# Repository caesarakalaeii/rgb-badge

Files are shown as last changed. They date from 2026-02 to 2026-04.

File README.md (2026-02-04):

# Ultra-High-Density RGB Matrix Badge

A wearable RGB matrix badge featuring 2560 individually addressable LEDs in a compact 100×65mm form factor.

## Project Overview

This project implements an ultra-dense LED matrix badge designed for human viewing (not camera-optimized) with parallel data lanes to achieve smooth 60+ FPS refresh rates. The design uses a two-board architecture separating the dense LED matrix from controller/power electronics for improved manufacturability and maintainability.

### Key Specifications

| Parameter | Value |
|---|---|
| Display Area | 100 mm × 65 mm |
| Resolution | 64 × 40 pixels (2560 total) |
| Pixel Pitch | 1.5625 mm (X) × 1.625 mm (Y) |
| Target Refresh Rate | 60+ FPS |
| Power Source | USB-C PD Powerbank |
| Quantity | ~10 boards |
| PCB Tool | KiCad |

## Hardware Architecture

### Two-Board Design

#### 1. Matrix PCB
- Dense 64×40 LED array
- Power distribution network
- Extensive decoupling capacitors
- Data lane entry points (8 lanes)
- Optimized for minimal rework risk

#### 2. Controller/Power PCB
- ESP32-S3 microcontroller
- USB-C Power Delivery circuitry
- Buck converter (PD voltage → 5V)
- 3.3V regulator for MCU
- Level shifters (3.3V → 5V for LED data)
- Power switch and protection
- Easy to iterate/upgrade without risking LED matrix

**Rationale:** Separating control from display allows safe iteration on USB/PD/MCU without risking the expensive, dense LED field.

## Component Selection

### LED: XINGLIGHT XL-1010RGBC-2812B

**Why this LED:**
- Cost: ~€0.03/pixel at volume (extremely competitive)
- Package: 1.0×1.0×0.8 mm (1010 SMD)
- Protocol: WS2812B-compatible (1-wire smart RGB)
- Supply: 3.5–5.5V (100% functional at 4.5–5.5V)
- PWM: ~1.0 kHz, 256 grayscale steps per channel
- Timing: ~1.2 µs per bit (~800 kbps class)

**Electrical Characteristics:**
- VDD: 3.5–5.5V (running at 5V)
- DIN VIH (min): 2.8V, VIL (max): 1.6V
- Optimized current: ~5 mA/channel → ~15 mA/pixel at full white
- Full array theoretical max: 2560 × 15 mA = 38.4A @ 5V (192W)

**Footprint Details:**
- 4× corner pads, 0.40 mm × 0.40 mm each
- Body-to-body clearance: ~0.56–0.63 mm at chosen pitch
- Minimal courtyard required for dense packing

### Microcontroller: ESP32-S3

**Selection criteria:**
- Sufficient GPIO for 8+ parallel data lanes
- DMA-capable for smooth LED updates
- Good headroom for complex animations
- 3.3V I/O (requires level shifting to 5V LEDs)
- Well-supported by Arduino/ESP-IDF ecosystems

### Power Architecture

#### Strategy: PD Negotiation → Buck Conversion

```
USB-C PD Powerbank (25000mAh, 145W class)
    ↓ (negotiated at 9V baseline, 12V/15V/20V optional)
Buck Converter
    ↓ (5V rail for LEDs)
LED Matrix (capped brightness in firmware)
    +
    ↓ (3.3V regulator)
ESP32-S3 + Logic
```

**PD Voltage Selection:**
- **Baseline: 9V PD** (maximum compatibility)
- Higher voltages (12V/15V/20V) reduce cable current but may not be universally available
- Buck converter sized for 8–12A continuous @ 5V (40–60W with safety margin)

**Rationale:**
- Reduces cable/connector current stress
- Provides stable 5V rail despite powerbank voltage
- Allows brightness capping in firmware to manage realistic power draw

## Data Distribution Architecture

### 8-Lane Parallel Design

**Mapping:**
- 8 data lanes, each driving 320 pixels
- Each lane: 8 columns × 40 rows
- Lanes arranged as vertical stripes across the 64-column display

**Refresh Math (per lane):**
```
1 pixel = 24 bits × 1.2 µs ≈ 28.8 µs
320 pixels ≈ 9.22 ms
+ Reset time (>200 µs) ≈ 9.4–9.8 ms total
→ Max refresh ≈ 100+ FPS per lane
```

**Actual target:** 60 FPS with comfortable headroom

### Signal Integrity

#### Level Shifting
- ESP32 outputs: 3.3V logic
- LED inputs: require high VIH @ 5V supply
- Solution: Fast 3.3V→5V level shifters, one per lane

#### Series Resistors (Multi-Purpose Protection)

**At level shifter output:**
- 33–68Ω close to shifter
- Purpose: Signal integrity, prevent overshoot/ringing on short traces

**Optional at matrix connector:**
- 220–500Ω (stuff if needed)
- Purpose: Protection against live-plug transients, cable inductance
- Datasheet recommends "protective resistors" and mentions 20Ω–2kΩ range

## PCB Design Considerations (KiCad)

### Matrix PCB Layout

#### LED Footprint Settings
```
Pads: 4× corner pads, 0.40mm × 0.40mm
Courtyard: Minimal (allow overlap for dense packing)
Soldermask: Conservative expansion per fab limits
Pitch: 1.5625mm (X) × 1.625mm (Y)
```

#### Placement Strategy
1. Create LED footprint with tight courtyard
2. Place first LED
3. Use **Rectangular Array Placement** for 64×40 grid
4. Disable clearance outline visualization in Appearance panel if needed
5. Verify soldermask web meets fab minimums

#### Decoupling Strategy

**Datasheet requirement:** "Decoupling capacitance between each LED is essential"

**Practical options:**
- **Aggressive:** 0201 ceramic per LED (2560 caps, likely on backside)
- **Practical:** Small cluster caps + per-lane bulk capacitors
- Requires via strategy for backside placement or dense front-side routing

### Power Distribution

**Primary concern:** Transients and current steps, not just average power

**Design for:**
- Fast load steps as LEDs switch between frames
- Large bulk capacitance on 5V rail near buck converter
- Low-impedance power distribution across matrix
- Star or mesh power routing to minimize voltage drop

**Enforcement:** Global brightness limiting in firmware to prevent exceeding powerbank capability

## Manufacturing Constraints

### Reflow Profile (from LED datasheet)
- Peak temperature: 260°C for 6 seconds maximum
- Maximum reflow cycles: 2
- **Implication:** Don't risk matrix board with unnecessary rework

### Hand Soldering (rework only)
- Iron: <30W, <300°C
- Contact time: <3 seconds per terminal
- **One touch per terminal maximum**

### Moisture Sensitivity
- Store sealed with desiccant
- After opening: use quickly in low humidity
- If compromised: bake at 60°C for 24 hours before use

**Recommendation:** Order LEDs in moisture-barrier bags, open only when ready for assembly, and complete assembly quickly.

## Development Roadmap

### Current Status: Design Phase

#### Completed
- [x] LED selection and validation
- [x] Architecture decisions (two-board, 8-lane)
- [x] Power strategy (PD negotiation + buck)
- [x] Footprint specifications from datasheet
- [x] Signal integrity approach

#### Next Steps

1. **KiCad Footprint Finalization**
   - Create LED footprint with datasheet-verified pad geometry
   - Validate courtyard settings for dense array placement
   - Test rectangular array placement for 64×40 grid

2. **Power Tree Design**
   - Define brightness cap (e.g., max 20W from bank)
   - Size buck converter and output capacitors
   - Calculate per-lane bulk capacitor requirements
   - Design power distribution network for matrix PCB

3. **Interconnect Definition**
   - Choose physical connection method (board-to-board, flex, cable)
   - Design lane-entry routing convention
   - Finalize connector footprints

4. **Schematic & Layout**
   - Controller/Power PCB schematic
   - Matrix PCB schematic (8 lane entry points + power)
   - Both PCB layouts with careful attention to:
     - Power distribution impedance
     - Signal integrity on data lanes
     - Thermal management (buck converter)
     - Mechanical alignment between boards

5. **Firmware Architecture**
   - ESP32-S3 parallel output driver using DMA
   - Brightness limiting enforcement
   - Animation framework
   - USB power negotiation handling

6. **Prototype & Test**
   - Order small batch (1-2 sets)
   - Validate assembly process
   - Test refresh rates and power consumption
   - Iterate before production run

## Bill of Materials (Estimated)

| Component | Quantity | Unit Cost | Total |
|---|---|---|---|
| XL-1010RGBC-2812B LED | 2560 | €0.03 | €76.80 |
| ESP32-S3 Module | 1 | ~€5 | €5 |
| Buck Converter IC + passives | 1 | ~€2-5 | €3.50 |
| Level Shifters (8ch) | 1-2 | ~€1 | €2 |
| PCBs (Matrix + Controller) | 2 | ~€30-50 | €40 |
| Connectors, passives, misc | - | - | €10-20 |
| **Total per badge (estimate)** | | | **~€140-150** |

*Note: Costs are rough estimates and will vary with supplier, quantity, and shipping.*

## References

- LED Datasheet: XINGLIGHT XL-1010RGBC-2812B (WS2812B protocol)
- MCU: ESP32-S3 Technical Reference Manual
- Target Powerbank: UGREEN Nexode 145W Max 25000mAh (or equivalent USB-C PD)

## Design Philosophy

**Key Principles:**
1. **Human-optimized, not camera-optimized** – No special PWM requirements for video compatibility
2. **Maintainability over integration** – Two-board design allows safe iteration
3. **Parallel over serial** – 8 data lanes enable smooth refresh without exotic protocols
4. **Design for manufacturing** – Minimize rework risk on dense LED matrix
5. **Power awareness** – Design for transients and steps, enforce limits in firmware

## License

This project is licensed under the GNU Affero General Public License v3.0 (AGPL-3.0) - see the [LICENSE](LICENSE) file for details.

## Contributors

- [@caesarakalaeii](https://github.com/caesarakalaeii) - Project creator and maintainer

---

**Project Status:** Active Development
**Last Updated:** 2026-02-04

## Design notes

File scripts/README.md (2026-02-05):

# KiCad LED Matrix Placement Scripts

Python scripts for automated placement of the 40×64 LED matrix in KiCad PCB Editor with VIA-optimized power distribution.

## Quick Start

### 1. Basic Placement Script

**File:** `place_led_matrix.py`

Simple row-major placement (left-to-right, top-to-bottom).

**Usage:**
1. Open your PCB in KiCad PCB Editor
2. Open scripting console: Tools → Scripting Console
3. Run:
   ```python
   exec(open('scripts/place_led_matrix.py').read())
   ```

### 2. Advanced Placement Script

**File:** `place_led_matrix_advanced.py`

Supports multiple placement patterns including the 8-lane serpentine pattern recommended in the README.

**Usage:**
1. Edit the script to choose your pattern:
   ```python
   PLACEMENT_PATTERN = "8lane_serpentine"  # or "row_major" or "serpentine"
   ```
2. Adjust starting position if needed:
   ```python
   START_X = 10.0  # mm from board origin
   START_Y = 10.0  # mm from board origin
   ```
3. Run in KiCad Scripting Console:
   ```python
   exec(open('scripts/place_led_matrix_advanced.py').read())
   ```

### 3. VIA-Optimized Placement Script (Recommended)

**File:** `place_led_matrix_via_optimized.py`

Optimized LED placement for shared power VIAs with 2×2 LED block pattern.

**Features:**
- 40 columns × 64 rows = 2560 LEDs
- 8 data lanes, each handling 8 rows × 40 columns (320 LEDs per lane)
- Serpentine routing within each lane for optimal data flow
- LEDs rotated in 2×2 blocks so VDD/GND pins face center
- Enables one shared VIA per 4 LEDs (640 VIAs total vs 2560)

**Target Pin Arrangement (2×2 block with center VIA):**
```
2 4 | 1 2
1 3 | 3 4
----V----
4 3 | 3 1
2 1 | 4 2
```
Where: 1=DOUT, 2=VDD, 3=GND, 4=DIN, V=shared VIA

**Usage:**
1. Adjust starting position and verify rotation angles:
   ```python
   START_X = 10.0
   START_Y = 10.0

   # Verify these match your footprint orientation
   BLOCK_ROTATIONS = {
       (True, True):   -90,   # Top-left
       (False, True):    0,   # Top-right
       (True, False):  180,   # Bottom-left
       (False, False):  90,   # Bottom-right
   }
   ```
2. Run in KiCad Scripting Console:
   ```python
   exec(open('scripts/place_led_matrix_via_optimized.py').read())
   ```
3. Verify LED orientations visually
4. Adjust BLOCK_ROTATIONS if pins don't align correctly

### 4. Shared VIA Placement Script

**File:** `place_power_vias.py`

Automatically places power VIAs in the center of each 2×2 LED block.

**Usage:**
1. **Run AFTER** running `place_led_matrix_via_optimized.py`
2. Verify configuration matches LED placement:
   ```python
   LED_COLS = 40
   LED_ROWS = 64
   VIA_SIZE = 0.4    # mm diameter
   VIA_DRILL = 0.2   # mm drill
   ```
3. Run in KiCad Scripting Console:
   ```python
   exec(open('scripts/place_power_vias.py').read())
   ```
4. Manually assign VIAs to VDD or GND nets as needed
5. Add power planes or heavy traces between VIAs

## Placement Patterns

### Row Major
- Simple left-to-right, top-to-bottom
- LED1 at top-left, LED2560 at bottom-right
- Longest data paths

### Serpentine
- Alternates direction each row
- Reduces trace length between rows
- Better for single-lane designs

### 8-Lane Serpentine (Recommended)
- Matches the README's 8 parallel data lanes architecture
- Each lane handles 8 columns × 40 rows (320 pixels)
- Serpentine routing within each lane
- Optimal for the parallel data distribution design

## Configuration

### For VIA-Optimized Scripts (Recommended)

Edit these variables in `place_led_matrix_via_optimized.py`:

```python
# Matrix size (VIA-optimized layout)
COLS = 40   # 40 columns
ROWS = 64   # 64 rows (8 data lanes × 8 rows each)
PITCH_X = 1.5625  # mm
PITCH_Y = 1.625   # mm

# Starting position (adjust for your board)
START_X = 10.0  # mm
START_Y = 10.0  # mm

# LED reference prefix (e.g., "D" for D1, D2, ...)
LED_PREFIX = "D"

# Block rotations for VIA optimization
BLOCK_ROTATIONS = {
    (True, True):   -90,   # Top-left LED in each 2×2 block
    (False, True):    0,   # Top-right LED
    (True, False):  180,   # Bottom-left LED
    (False, False):  90,   # Bottom-right LED
}
```

### For Legacy Scripts

Edit these variables in `place_led_matrix.py` or `place_led_matrix_advanced.py`:

```python
# Matrix size (legacy layout)
COLS = 64
ROWS = 40
PITCH_X = 1.5625  # mm
PITCH_Y = 1.625   # mm

# Starting position (adjust for your board)
START_X = 10.0  # mm
START_Y = 10.0  # mm

# LED reference prefix (e.g., "D" for D1, D2, ...)
LED_PREFIX = "D"

# Rotation (degrees)
LED_ROTATION = 0.0
```

## Prerequisites

### Footprint Naming
LEDs must be named sequentially:
- LED1, LED2, LED3, ..., LED2560

### Component Import
Before running placement:
1. Create schematic with 2560 LED symbols
2. Assign footprints to all LEDs
3. Update PCB from schematic (Tools → Update PCB from Schematic)
4. All 2560 LEDs should now be on the PCB (likely in a pile)

## Workflow

### Method 1: VIA-Optimized Workflow (Recommended)

1. **Design schematic** with 2560 LED symbols
   - Use hierarchical sheets or array annotations if needed
   - Assign XL-1010RGBC-2812B footprint to all
   - Add connectors: J1 (data lines) and J2 (VDD/GND)

2. **Update PCB from schematic**
   - All LEDs import as a stack at origin

3. **Run LED placement script**
   - `exec(open('scripts/place_led_matrix_via_optimized.py').read())`
   - Verify LED orientations match intended 2×2 block pattern

4. **Run VIA placement script**
   - `exec(open('scripts/place_power_vias.py').read())`
   - Places 640 shared VIAs in 2×2 block centers

5. **Power distribution**
   - Assign VIAs to VDD/GND nets
   - Add power planes on inner layers
   - Connect J2 (power connector) to power distribution

6. **Data routing**
   - Route 8 data lanes from J1 (data connector)
   - Each lane: 8 rows × 40 LEDs in serpentine pattern
   - Add series resistors on data lines if needed

### Method 2: Legacy Import then Auto-Place

1. **Design schematic** with 2560 LED symbols
   - Use hierarchical sheets or array annotations if needed
   - Assign XL-1010RGBC-2812B footprint to all

2. **Update PCB from schematic**
   - All LEDs import as a stack at origin

3. **Run placement script**
   - Opens them into perfect matrix

4. **Route**
   - Add data traces, power planes, decoupling caps

### Method 2: Place-as-you-go

1. Place first LED manually at desired start position
2. Note its exact position
3. Update script `START_X` and `START_Y` to match
4. Import remaining LEDs
5. Run script to arrange all

## Expected Output

### VIA-Optimized Script

```
Placing 2560 LEDs in VIA-optimized pattern
Matrix: 40 columns × 64 rows
Pitch: 1.5625mm × 1.625mm
Pattern: 8-lane serpentine with 2×2 block VIA optimization
Starting position: (10.0, 10.0)

  Using VIA-optimized 8-lane serpentine pattern
  Layout: 40 columns × 64 rows = 2560 LEDs
  Data lanes: 8 lanes × 320 pixels
  Each lane: 8 rows × 40 columns
  2×2 block rotations for shared center VIAs

  Placed 100/2560 LEDs...
  Placed 200/2560 LEDs...
  ...
  Placed 2560/2560 LEDs...

✓ Successfully placed 2560 LEDs

Matrix dimensions:
  Width: 60.938 mm (40 columns)
  Height: 102.375 mm (64 rows)
  Total area: 60.9 × 102.4 mm
  End position: (70.938, 112.375)

  VIA optimization: LEDs grouped in 2×2 blocks
  - 640 shared VIAs possible
  - Each VIA serves 4 LEDs (VDD + GND)

Done! Board refreshed.
```

### Legacy Script

```
Placing 2560 LEDs in 64×40 matrix
Pitch: 1.5625mm × 1.625mm
Pattern: 8lane_serpentine
Starting position: (10.0, 10.0)

  Using 8-lane serpentine: 8 lanes × 320 pixels
  Each lane: 8 columns × 40 rows
  Placed 100/2560 LEDs...
  Placed 200/2560 LEDs...
  ...
  Placed 2560/2560 LEDs...

✓ Successfully placed 2560 LEDs

Matrix dimensions:
  Width: 98.438 mm (64 columns)
  Height: 63.375 mm (40 rows)
  Total area: 98.4 × 63.4 mm
  End position: (108.438, 73.375)

Done! Board refreshed.
```

## Troubleshooting

### "Found X LEDs, expected 2560"
- Check that all LEDs are named with correct prefix
- Verify LED_PREFIX variable matches your naming
- Run anyway if you're testing with fewer LEDs

### LEDs appear off-board
- Adjust START_X and START_Y values
- Check board origin (some boards use center, others use corner)

### Script doesn't run
- Verify file path is correct (relative to KiCad project)
- Use absolute path if needed:
  ```python
  exec(open('/home/caesar/git/rgb-badge/scripts/place_led_matrix.py').read())
  ```

### Position conflicts/overlaps
- Verify PITCH_X and PITCH_Y are correct
- Check that footprint courtyard isn't causing false conflicts
- May need to disable courtyard visibility: View → Appearance → Graphic Items → Footprint Courtyard

## Physical Verification

### VIA-Optimized Layout (40×64)

After placement, verify:
- Total matrix width: ~60.94 mm (40 columns)
- Total matrix height: ~102.38 mm (64 rows)
- Body-to-body clearance: 0.56–0.63 mm (as specified in README)
- VIA positions: centered between each 2×2 LED block
- VDD/GND pins oriented toward center VIAs in each 2×2 block

### Legacy Layout (64×40)

After placement, verify:
- Total matrix width: ~98.44 mm (64 columns, matches README: 100mm including margins)
- Total matrix height: ~63.38 mm (40 rows, matches README: 65mm including margins)
- Body-to-body clearance: 0.56–0.63 mm (as specified in README)

## Next Steps

### After VIA-Optimized Placement

1. **Place and route power VIAs** (use `place_power_vias.py`)
2. **Add power distribution network**
   - Connect J2 connector (VDD/GND) to power planes
   - Use inner layers for power planes
   - Heavy traces or copper pours between VIAs
3. **Add decoupling capacitors** (per 2×2 block or per LED row)
4. **Route 8 data lanes**
   - Connect J1 connector (8 data inputs) to start of each lane
   - Follow serpentine pattern within each lane
   - Add series resistors (220-470Ω) on each data line
5. **Verify LED orientations**
   - Check that VDD/GND pins face center VIAs in each 2×2 block
   - Adjust BLOCK_ROTATIONS if needed
6. **Add soldermask and silkscreen**
7. **DRC check** focusing on soldermask webbing between pads
8. **Generate Gerbers**

### After Legacy Placement

1. Add power distribution network
2. Add decoupling capacitors (per LED or per cluster)
3. Route data lanes from connector to lane entry points
4. Add soldermask and silkscreen
5. DRC check focusing on soldermask webbing between pads
6. Generate Gerbers

## License

Part of the Ultra-High-Density RGB Matrix Badge project (AGPL-3.0)

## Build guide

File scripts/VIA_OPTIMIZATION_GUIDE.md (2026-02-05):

# VIA-Optimized LED Matrix Layout Guide

## Overview

This document explains the VIA-optimized LED placement pattern that reduces the number of power VIAs from 2560 to 640 by sharing VIAs between groups of 4 LEDs.

## Layout Dimensions

- **Total LEDs:** 2560 (same as before)
- **Matrix size:** 40 columns × 64 rows
- **Data lanes:** 8 lanes, each handling 8 rows × 40 columns = 320 LEDs
- **VIA blocks:** 20 × 32 = 640 shared VIAs

## Data Flow Pattern

```
Lane 1 (Rows 0-7):
  Row 0: D1 →→→→→→→→→→→→→→→→→→→→→→→→→→→→→→→→→→→→→→→ D40
  Row 1: D80 ←←←←←←←←←←←←←←←←←←←←←←←←←←←←←←←←←←←←←←← D41
  Row 2: D81 →→→→→→→→→→→→→→→→→→→→→→→→→→→→→→→→→→→→→→ D120
  Row 3: D160 ←←←←←←←←←←←←←←←←←←←←←←←←←←←←←←←←←←←←←← D121
  ...
  Row 7: D280 ←←←←←←←←←←←←←←←←←←←←←←←←←←←←←←←←←←←←←← D241

Lane 2 (Rows 8-15):
  Row 8: D281 →→→→→→→→→→→→→→→→→→→→→→→→→→→→→→→→→→→→→ D320
  Row 9: D360 ←←←←←←←←←←←←←←←←←←←←←←←←←←←←←←←←←←←←←← D321
  ...

... (Lanes 3-7) ...

Lane 8 (Rows 56-63):
  Row 56: D2241 →→→→→→→→→→→→→→→→→→→→→→→→→→→→→→→→→→→ D2280
  Row 57: D2320 ←←←←←←←←←←←←←←←←←←←←←←←←←←←←←←←←←←←←← D2281
  ...
  Row 63: D2560 ←←←←←←←←←←←←←←←←←←←←←←←←←←←←←←←←←←←←← D2521
```

## 2×2 LED Block with Shared VIA

### Pin Numbering
- Pin 1: DOUT (data output)
- Pin 2: VDD (power)
- Pin 3: GND (ground)
- Pin 4: DIN (data input)

### Target Pin Arrangement

Each 2×2 block of LEDs is rotated so that VDD (pin 2) and GND (pin 3) face toward the center VIA:

```
╔════════════════╦════════════════╗
║  LED (col 0,   ║  LED (col 1,   ║
║     row 0)     ║     row 0)     ║
║                ║                ║
║   2----4       ║   1----2       ║
║   |    |       ║   |    |       ║
║   1----3       ║   3----4       ║
║           ●━━━━╋━━━●            ║
║           ┃    ║    ┃           ║
╠═══════════╬════╬════╬═══════════╣
║           ┃    ║    ┃           ║
║           ●━━━━╋━━━●            ║
║   4----3       ║   3----1       ║
║   |    |       ║   |    |       ║
║   2----1       ║   4----2       ║
║                ║                ║
║  LED (col 0,   ║  LED (col 1,   ║
║     row 1)     ║     row 1)     ║
╚════════════════╩════════════════╝

         ■ = Shared VIA (center)
         ● = VDD/GND pins facing VIA
```

### Pin Positions in Each Block Position

**Top-Left LED (col even, row even):**
```
2  4    ← Rotation: -90°
1  3
```
- Pins 2,3 (VDD/GND) face RIGHT and DOWN toward center

**Top-Right LED (col odd, row even):**
```
1  2    ← Rotation: 0°
3  4
```
- Pins 2,3 (VDD/GND) face LEFT and DOWN toward center

**Bottom-Left LED (col even, row odd):**
```
4  3    ← Rotation: 180°
2  1
```
- Pins 2,3 (VDD/GND) face RIGHT and UP toward center

**Bottom-Right LED (col odd, row odd):**
```
3  1    ← Rotation: 90°
4  2
```
- Pins 2,3 (VDD/GND) face LEFT and UP toward center

## VIA Placement

VIAs are placed at the CENTER of each 2×2 LED block:

- VIA X position: `LED_START_X + (via_col × 2 × PITCH_X) + (PITCH_X / 2)`
- VIA Y position: `LED_START_Y + (via_row × 2 × PITCH_Y) + (PITCH_Y / 2)`

Where:
- `via_col` = 0 to 19 (20 VIA columns)
- `via_row` = 0 to 31 (32 VIA rows)
- `PITCH_X` = 1.5625 mm
- `PITCH_Y` = 1.625 mm

## Connector Pinout

### J1 - Data Connector (8 pins)
```
Pin 1: Data Lane 1 (Rows 0-7)
Pin 2: Data Lane 2 (Rows 8-15)
Pin 3: Data Lane 3 (Rows 16-23)
Pin 4: Data Lane 4 (Rows 24-31)
Pin 5: Data Lane 5 (Rows 32-39)
Pin 6: Data Lane 6 (Rows 40-47)
Pin 7: Data Lane 7 (Rows 48-55)
Pin 8: Data Lane 8 (Rows 56-63)
```

### J2 - Power Connector (2 pins)
```
Pin 1: VDD (+5V)
Pin 2: GND
```

## Advantages of This Layout

1. **Reduced VIA count:** 640 VIAs instead of 2560 (75% reduction)
2. **Simpler power routing:** Fewer VIAs to connect to power planes
3. **Better power distribution:** Shared VIAs provide natural star topology
4. **Maintains data integrity:** Serpentine pattern keeps data paths short
5. **Easier assembly:** Fewer drill holes, faster manufacturing

## Power Distribution Strategy

1. **Inner layer 1:** VDD power plane
2. **Inner layer 2:** GND power plane
3. **VIAs connect through all layers**
4. **Top/bottom layers:** Data traces and local power connections

### Recommended Routing

- Use 0.4mm VIA diameter, 0.2mm drill
- Connect J2 to power planes with heavy traces (1-2mm width)
- Add decoupling capacitors:
  - Option 1: One 100nF cap per 2×2 LED block (640 caps)
  - Option 2: One 100nF cap per row (64 caps)
  - Option 3: One 470nF cap per data lane (8 caps)

## Verification Checklist

- [ ] All LEDs placed in correct serpentine order
- [ ] LED rotations match 2×2 block pattern
- [ ] VDD/GND pins oriented toward center VIAs
- [ ] 640 VIAs placed at block centers
- [ ] VIAs assigned to correct nets (VDD or GND)
- [ ] Data lanes routed in serpentine pattern
- [ ] Series resistors added to data lines (220-470Ω)
- [ ] Decoupling capacitors placed near power VIAs
- [ ] Power planes on inner layers
- [ ] J1 and J2 connectors placed and routed

## Troubleshooting

### LEDs not oriented correctly
- Adjust `BLOCK_ROTATIONS` dict in `place_led_matrix_via_optimized.py`
- Values depend on your specific footprint orientation
- Test with a small section first (4×4 LEDs)

### VIAs not aligning with LED pins
- Check `PITCH_X` and `PITCH_Y` values match LED spacing
- Verify `START_X` and `START_Y` match between LED and VIA scripts
- VIA offset should be exactly half-pitch in both directions

### Data flow incorrect
- Verify serpentine pattern: even rows L→R, odd rows R→L
- Check lane boundaries: each lane is exactly 8 rows
- Confirm LED numbering matches schematic

## References

- `place_led_matrix_via_optimized.py` - LED placement script
- `place_power_vias.py` - VIA placement script
- `README.md` - General documentation and workflow
- XL-1010RGBC-WS2812B datasheet: https://datasheet.lcsc.com/lcsc/2301111010_XINGLIGHT-XL-1010RGBC-WS2812B_C5349953.pdf

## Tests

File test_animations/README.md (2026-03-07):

# Snake Animation for ESP32 with 10x10 LED Matrix

## Hardware Setup
- **LED Matrix:** 10x10 (100 LEDs total)
- **Data Pins:**
  - D13 (GPIO 13) - First 50 LEDs
  - D12 (GPIO 12) - Second 50 LEDs
- **LED Type:** WS2812B (addressable RGB)
- **Board:** ESP32

## Features
- **Snake Game Animation:** Automatically navigating snake
- **Color-Changing Snake:** Snake changes color to match the food it eats
- **Cycling Food Colors:** Food continuously cycles through the full color spectrum
- **Auto-Wrap:** Snake wraps around screen edges
- **Game Over:** Restarts automatically when snake hits itself

## Installation

### Method 1: PlatformIO (Recommended)

**Quick Start:**
```bash
# Install PlatformIO and setup environment
./setup.sh

# Build and flash to ESP32
./flash.sh

# Build, flash, and open serial monitor
./flash.sh -m
```

**Available Options:**
```bash
./flash.sh              # Build and flash
./flash.sh -m           # Build, flash, and monitor
./flash.sh -c           # Clean build first
./flash.sh -p /dev/ttyUSB0  # Specify port
./flash.sh --help       # Show all options
```

**Manual PlatformIO Installation:**
```bash
# Install PlatformIO
pip install platformio

# Build project
pio run

# Upload to ESP32
pio run --target upload

# Open serial monitor
pio device monitor
```

### Method 2: Arduino IDE

1. Install the FastLED library:
   - Go to **Sketch → Include Library → Manage Libraries**
   - Search for "FastLED"
   - Install "FastLED by Daniel Garcia"
2. Open `src/main.cpp` (or rename to `.ino`)
3. Select ESP32 board from **Tools → Board**
4. Select COM port from **Tools → Port**
5. Click Upload

## Configuration

### Adjustable Parameters
```cpp
#define SNAKE_SPEED 200        // Speed in milliseconds (lower = faster)
#define INITIAL_SNAKE_LENGTH 3 // Starting snake length
FastLED.setBrightness(50);     // LED brightness (0-255)
```

### LED Layout
The code assumes a serpentine/zigzag layout:
```
→ → → → → → → → → →
                    ↓
← ← ← ← ← ← ← ← ← ←
↓
→ → → → → → → → → →
```

If your matrix has a different layout, you may need to adjust the `setPixel()` function.

## How It Works
1. Snake starts at position (5,5) moving right
2. Food appears at random positions with cycling colors
3. Snake automatically navigates toward food
4. When snake eats food, it grows and changes to food's color
5. Game ends if snake collides with itself, then auto-restarts

## Troubleshooting

### LEDs not lighting up
- Check power supply (WS2812B needs 5V, adequate current)
- Verify GPIO pin connections (D13 = GPIO13, D12 = GPIO12)
- Check LED strip data direction

### Wrong colors or patterns
- Verify `LED_TYPE` and `COLOR_ORDER` in code
- Some strips use RGB instead of GRB order
- Adjust serpentine pattern in `setPixel()` if needed

### Compilation errors
- Ensure FastLED library is installed
- Select ESP32 board (not Arduino boards)
- Update Arduino ESP32 board package if needed

## Serial Monitor
Open Serial Monitor (115200 baud) to see game status:
- Food eaten events
- Snake length updates
- Game over notifications

## Alternative: Using with WLED
This is a standalone sketch. If you want to use WLED firmware instead:
- Flash WLED to ESP32
- Use WLED's built-in effects via web interface
- Note: WLED doesn't have a snake game effect built-in
- You would need to create a custom WLED usermod for this animation

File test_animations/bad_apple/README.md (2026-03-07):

# Bad Apple RGB Edition for 10x10 LED Matrix

A colorful version of the iconic Bad Apple animation running on ESP32 with a 10x10 RGB LED matrix.

## Features

- **6 Color Modes:**
  - Classic Black & White
  - Rainbow Cycle
  - Pulsing Pink/Purple
  - Fire Effect (red-orange-yellow)
  - Matrix Green
  - Ocean Waves (blue-cyan)

- **Auto-looping** with color mode changes
- **20 FPS** smooth playback
- **~6500 frames** of animation
- **LittleFS storage** for efficient data access

## Hardware Setup

- **ESP32 Dev Board**
- **10x10 RGB LED Matrix** (WS2812B)
  - Data line 1: GPIO 13 (first 50 LEDs)
  - Data line 2: GPIO 12 (second 50 LEDs)
- **5V Power Supply** (adequate current for 100 LEDs)

## Quick Start (One Command!)

```bash
./setup_and_flash.sh
```

This will:
1. Install Python dependencies
2. Download and convert Bad Apple video
3. Build firmware
4. Flash to ESP32
5. Upload filesystem data

That's it! The animation will start playing automatically.

## Manual Setup (Step by Step)

### 1. Install Dependencies

**Using virtual environment (recommended):**
```bash
cd ..
python3 -m venv .venv
source .venv/bin/activate
pip install -r requirements.txt
```

**Or system-wide:**
```bash
pip install opencv-python numpy pillow requests tqdm
```

**PlatformIO:**
```bash
pip install platformio
```

### 2. Convert Video to Frame Data

**Easy way:**
```bash
cd ..
./convert_with_venv.sh  # Handles venv automatically
```

**Or manually:**
```bash
cd ..
source .venv/bin/activate  # If using venv
python bad_apple_converter.py
deactivate  # If using venv
```

This will:
- Download Bad Apple video (~16MB)
- Convert to 10x10 resolution
- Generate `bad_apple_data/bad_apple_frames.bin`
- Create preview images

### 3. Copy Data to Project

```bash
cd bad_apple
mkdir -p data
cp ../bad_apple_data/bad_apple_frames.bin data/
```

### 4. Build and Flash

```bash
# Build and flash firmware
pio run --target upload

# Upload filesystem (contains frame data)
pio run --target uploadfs
```

### 5. Watch It Play!

```bash
pio device monitor
```

## Using the Flash Scripts

**Quick flash:**
```bash
./flash.sh
```

**With serial monitor:**
```bash
./flash.sh -m
```

**Upload filesystem only:**
```bash
./flash.sh -f
```

## Color Modes

The animation automatically cycles through different color modes each time it loops:

| Mode | Description | Visual Effect |
|---|---|---|
| 0 | Classic | Traditional black and white |
| 1 | Rainbow | Full spectrum color cycling |
| 2 | Pulse | Pulsing pink/purple |
| 3 | Fire | Random orange/red flames |
| 4 | Matrix | Classic Matrix green |
| 5 | Ocean | Blue-cyan waves |

## Technical Details

### Frame Format
- **Resolution:** 10x10 pixels (100 pixels total)
- **Encoding:** 1 bit per pixel (monochrome)
- **Storage:** 13 bytes per frame
- **Total size:** ~85KB (6500 frames)
- **Frame rate:** 20 FPS
- **Duration:** ~5.4 minutes

### File Structure
```
bad_apple_frames.bin:
  Header (6 bytes):
    - uint16_t: frame count
    - uint8_t:  FPS
    - uint8_t:  width (10)
    - uint8_t:  height (10)
    - uint8_t:  padding
  Frames (13 bytes each):
    - 100 pixels packed into 13 bytes
    - MSB first, row-major order
```

### Memory Usage
- **Flash:** ~85KB for frame data
- **RAM:** <1KB (single frame buffer)
- **Program:** ~300KB

## Troubleshooting

### "LittleFS initialization failed"
- Make sure you ran: `pio run --target uploadfs`
- Try: `./flash.sh -f` to re-upload filesystem

### "Failed to open data file"
1. Check data folder exists: `ls data/`
2. Verify file: `ls -lh data/bad_apple_frames.bin`
3. Re-run converter: `python3 ../bad_apple_converter.py`
4. Re-upload: `pio run --target uploadfs`

### "Upload failed" or "Permission denied"
```bash
# Add user to dialout group (Linux)
sudo usermod -a -G dialout $USER
# Log out and back in

# Or specify port manually
pio run --target upload --upload-port /dev/ttyUSB0
```

### Video plays too fast/slow
Adjust `BA_FRAME_MS` in `src/main.cpp`:
```cpp
#define BA_FRAME_MS 50  // 50ms = 20 FPS, increase for slower
```

### Wrong colors or brightness
Adjust in `setup()`:
```cpp
FastLED.setBrightness(80);  // 0-255
```

### LEDs not responding
- Check power supply (5V, adequate amperage)
- Verify GPIO connections (13 and 12)
- Test LED strip direction
- Check wiring layout (serpentine pattern expected)

## Customization

### Add More Color Modes

Edit `getColorForMode()` in `src/main.cpp`:

```cpp
case MODE_CUSTOM:
  return CHSV(hue, saturation, brightness);
```

Don't forget to update `MODE_COUNT`.

### Change Layout

If your matrix has different wiring, modify `setPixel()`:

```cpp
// For non-serpentine layout:
int ledIndex = y * MATRIX_WIDTH + x;
```

### Disable Looping

In `setup()`:
```cpp
bool loopVideo = false;
```

### Manual Color Mode Control

Replace `nextColorMode()` call with specific mode:
```cpp
colorMode = MODE_FIRE;  // Lock to fire mode
```

## Credits

- **Bad Apple!!** - Original video from Touhou Project
- **FastLED** - LED control library
- **Archive.org** - Video source

## What is Bad Apple?

Bad Apple is a famous music video from the Touhou Project series featuring distinctive black-and-white silhouette animation. It became an internet phenomenon and a popular benchmark for demonstrating display capabilities on various hardware platforms, from oscilloscopes to graphing calculators.

## License

This project is for educational and personal use. The Bad Apple video content belongs to its original creators.

## Additional Resources

- [Bad Apple on Know Your Meme](https://knowyourmeme.com/memes/bad-apple)
- [FastLED Documentation](https://fastled.io/)
- [PlatformIO Documentation](https://docs.platformio.org/)

## Support

Having issues? Check:
1. Serial monitor output for error messages
2. File sizes match expected values
3. All dependencies installed correctly
4. ESP32 properly powered

Enjoy the show! 🍎✨

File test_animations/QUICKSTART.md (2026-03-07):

# Quick Start Guide

## 1. Setup (First Time Only)
```bash
cd test_animations
./setup.sh
```

## 2. Flash to ESP32
```bash
# Connect ESP32 via USB, then:
./flash.sh
```

## 3. Watch It Run
```bash
# To see serial output:
./flash.sh -m
```

## Alternative: Using Make
```bash
make setup        # First time only
make flash        # Build and upload
make monitor      # View serial output
```

## Troubleshooting

**"Permission denied" error:**
```bash
sudo usermod -a -G dialout $USER
# Then log out and back in
```

**"Device not found" error:**
```bash
# List available ports:
pio device list

# Flash to specific port:
./flash.sh -p /dev/ttyUSB0
```

**Need to rebuild from scratch:**
```bash
./flash.sh -c    # Clean and rebuild
```

That's it! The snake should start playing automatically.

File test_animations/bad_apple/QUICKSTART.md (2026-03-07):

# Bad Apple RGB - Quick Start

## One-Line Setup

```bash
./setup_and_flash.sh
```

Done! The animation will start automatically.

---

## Alternative: Using Make

```bash
make all          # Does everything
make monitor      # Watch serial output
```

---

## Manual Steps (if you prefer)

### 1. Convert Video (with venv)
```bash
cd ..
./convert_with_venv.sh
cd bad_apple
```

Or manually:
```bash
cd ..
python3 -m venv .venv
source .venv/bin/activate
pip install -r requirements.txt
python bad_apple_converter.py
deactivate
cd bad_apple
```

### 3. Copy Data
```bash
mkdir -p data
cp ../bad_apple_data/bad_apple_frames.bin data/
```

### 4. Flash Everything
```bash
pio run --target upload      # Firmware
pio run --target uploadfs    # Data
```

---

## Troubleshooting

**"LittleFS init failed"**
```bash
pio run --target uploadfs
```

**"Permission denied"**
```bash
sudo usermod -a -G dialout $USER
# Then log out and back in
```

**"Port not found"**
```bash
pio device list
pio run --target upload --upload-port /dev/ttyUSB0
```

---

## What You'll See

- **Duration:** ~5.4 minutes
- **Frame rate:** 20 FPS
- **Resolution:** 10×10 pixels
- **Color modes:** Cycles through 6 different color schemes
  - Classic B&W
  - Rainbow
  - Pulsing Pink
  - Fire Effect
  - Matrix Green
  - Ocean Blue

The animation loops forever with different colors each time!

---

## Quick Commands

```bash
# See what's happening
pio device monitor

# Re-flash firmware only
./flash.sh

# Re-upload data only
./flash.sh -f

# Flash and monitor
./flash.sh -m
```

That's it! 🍎✨

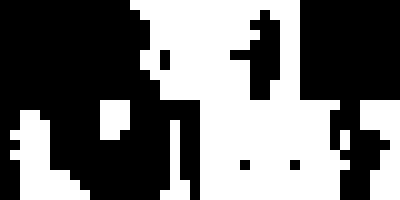
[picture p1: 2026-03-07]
test_animations/bad_apple_data/sample_frames.png

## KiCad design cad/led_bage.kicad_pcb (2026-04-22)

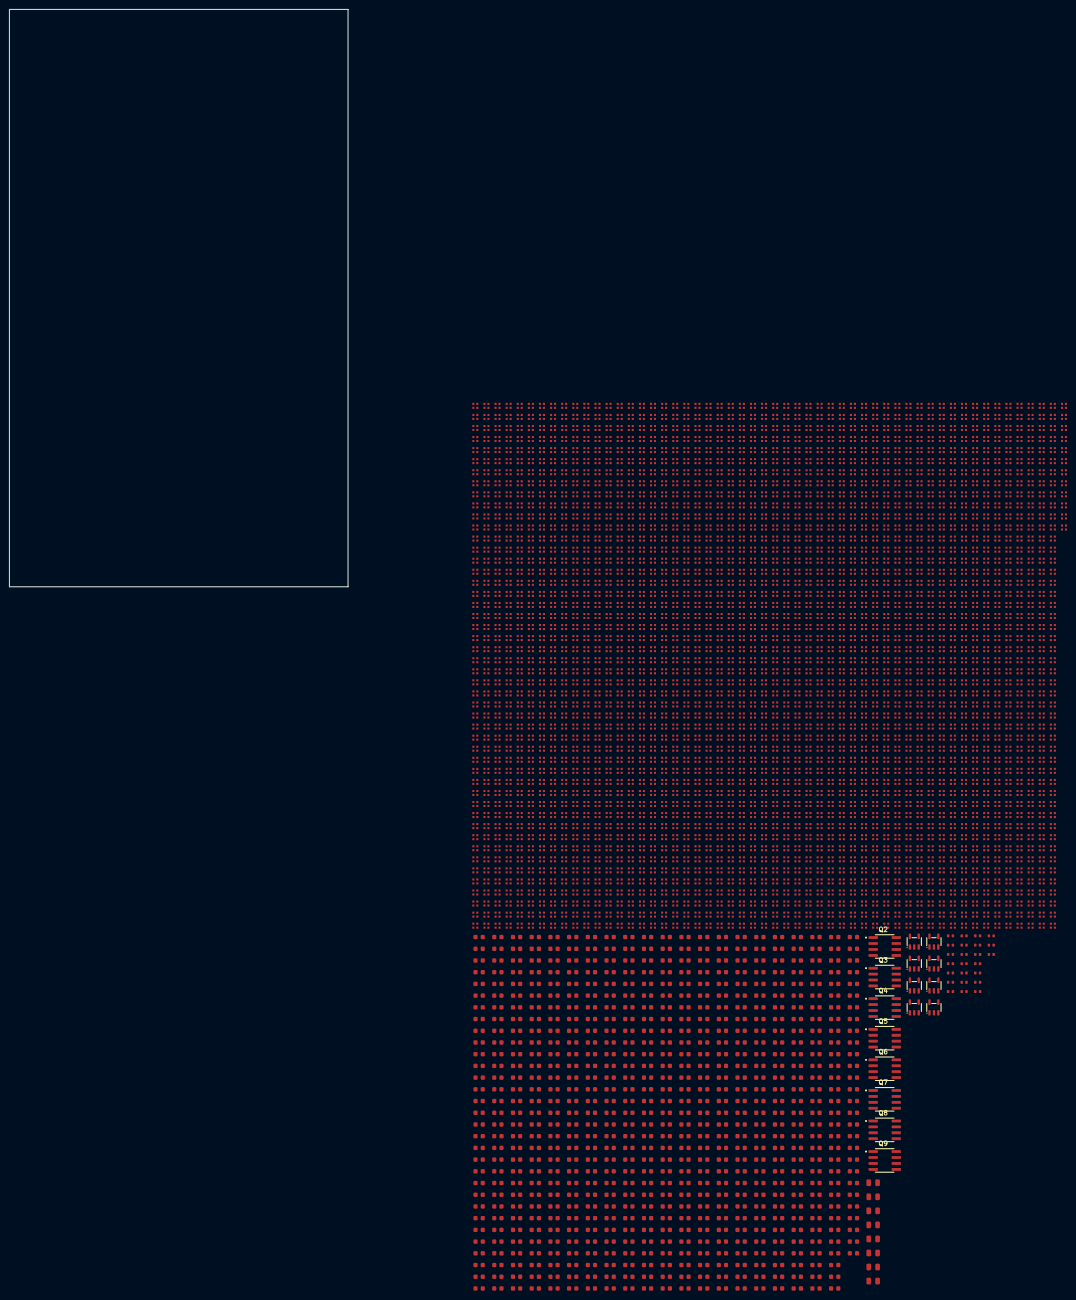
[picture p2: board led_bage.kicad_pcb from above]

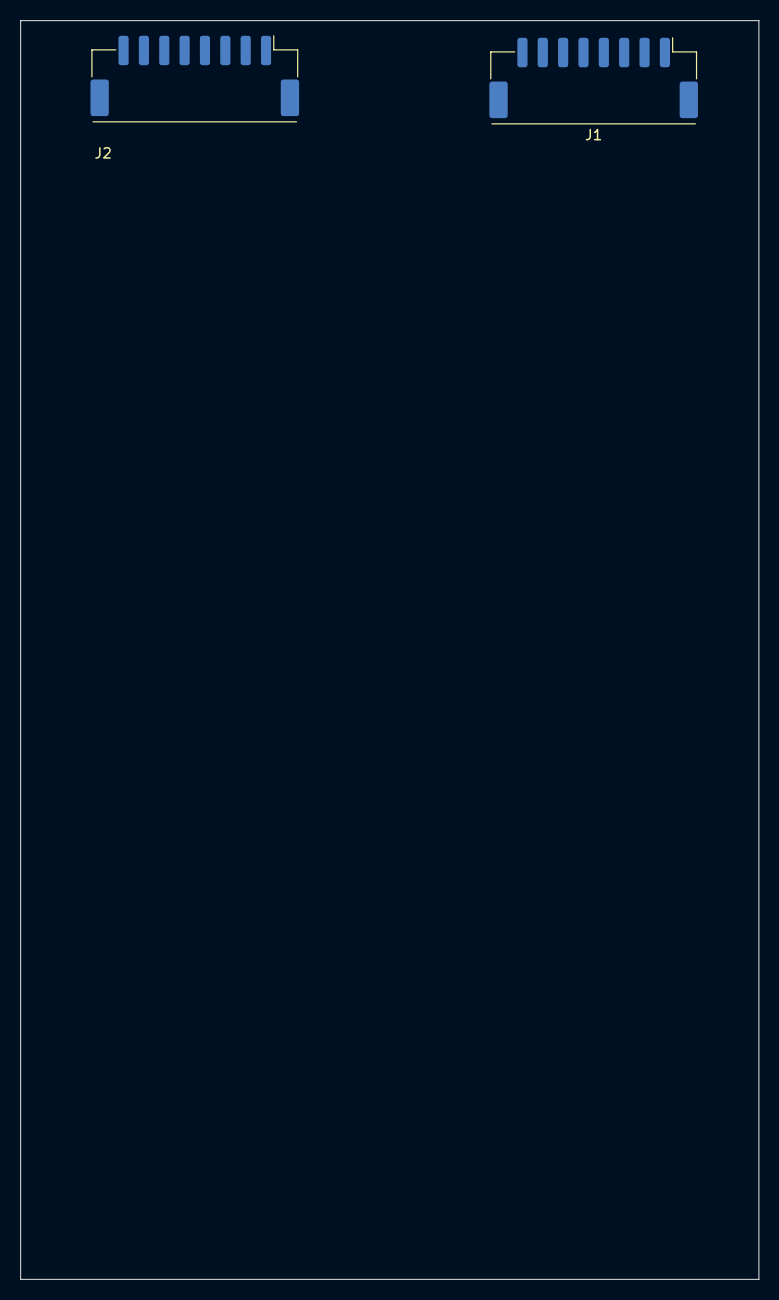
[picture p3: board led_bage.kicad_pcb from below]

Board: 4 copper layers, 72.6 x 123.7 mm, 3254 parts (2 on the bottom side), 2576 nets, no tracks yet.

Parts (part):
C1, C2, C3, C4, C5, C6, C7, C8, C9, C10, C11, C12, C13, C14, C15, C16, C17, C18, C19, C20, C21, C22, C23, C24, C25, C35, C36, C37, C38, C39, C40, C41, C42, C43, C44, C45, C46, C47, C48, C49, C50, C51, C52, C53, C54, C55, C56, C57, C58, C59, C60, C61, C62, C63, C64, C65, C66, C67, C68, C69, C70, C71, C72, C73, C74, C75, C76, C77, C78, C79, C80, C81, C82, C83, C84, C85, C86, C87, C88, C89, C90, C91, C92, C93, C94, C95, C96, C97, C98, C99, C100, C101, C102, C103, C104, C105, C106, C107, C108, C109, C110, C111, C112, C113, C114, C115, C116, C117, C118, C119, C120, C121, C122, C123, C124, C125, C126, C127, C128, C129, C130, C131, C132, C133, C134, C135, C136, C137, C138, C139, C140, C141, C142, C143, C144, C145, C146, C147, C148, C149, C150, C151, C152, C153, C154, C155, C156, C157, C158, C159, C160, C161, C162, C163, C164, C165, C166, C167, C168, C169, C170, C171, C172, C173, C174, C175, C176, C177, C178, C179, C180, C181, C182, C183, C184, C185, C186, C187, C188, C189, C190, C191, C192, C193, C194, C195, C196, C197, C198, C199, C200, C201, C202, C203, C204, C205, C206, C207, C208, C209, C210, C211, C212, C213, C214, C215, C216, C217, C218, C219, C220, C221, C222, C223, C224, C225, C226, C227, C228, C229, C230, C231, C232, C233, C234, C235, C236, C237, C238, C239, C240, C241, C242, C243, C244, C245, C246, C247, C248, C249, C250, C251, C252, C253, C254, C255, C256, C257, C258, C259, C260, C261, C262, C263, C264, C265, C266, C267, C268, C269, C270, C271, C272, C273, C274, C275, C276, C277, C278, C279, C280, C281, C282, C283, C284, C285, C286, C287, C288, C289, C290, C291, C292, C293, C294, C295, C296, C297, C298, C299, C300, C301, C302, C303, C304, C305, C306, C307, C308, C309, C310, C311, C312, C313, C314, C315, C316, C317, C318, C319, C320, C321, C322, C323, C324, C325, C326, C327, C328, C329, C330, C331, C332, C333, C334, C335, C336, C337, C338, C339, C340, C341, C342, C343, C344, C345, C346, C347, C348, C349, C350, C351, C352, C353, C354, C355, C356, C357, C358, C359, C360, C361, C362, C363, C364, C365, C366, C367, C368, C369, C370, C371, C372, C373, C374, C375, C376, C377, C378, C379, C380, C381, C382, C383, C384, C385, C386, C387, C388, C389, C390, C391, C392, C393, C394, C395, C396, C397, C398, C399, C400, C401, C402, C403, C404, C405, C406, C407, C408, C409, C410, C411, C412, C413, C414, C415, C416, C417, C418, C419, C420, C421, C422, C423, C424, C425, C426, C427, C428, C429, C430, C431, C432, C433, C434, C435, C436, C437, C438, C439, C440, C441, C442, C443, C444, C445, C446, C447, C448, C449, C450, C451, C452, C453, C454, C455, C456, C457, C458, C459, C460, C461, C462, C463, C464, C465, C466, C467, C468, C469, C470, C471, C472, C473, C474, C475, C476, C477, C478, C479, C480, C481, C482, C483, C484, C485, C486, C487, C488, C489, C490, C491, C492, C493, C494, C495, C496, C497, C498, C499, C500, C501, C502, C503, C504, C505, C506, C507, C508, C509, C510, C511, C512, C513, C514, C515, C516, C517, C518, C519, C520, C521, C522, C523, C524, C525, C526, C527, C528, C529, C530, C531, C532, C533, C534, C535, C536, C537, C538, C539, C540, C541, C542, C543, C544, C545, C546, C547, C548, C549, C550, C551, C552, C553, C554, C555, C556, C557, C558, C559, C560, C561, C562, C563, C564, C565, C566, C567, C568, C569, C570, C571, C572, C573, C574, C575, C576, C577, C578, C579, C580, C581, C582, C583, C584, C585, C586, C587, C588, C589, C590, C591, C592, C593, C594, C595, C596, C597, C598, C599, C600, C601, C602, C603, C604, C605, C606, C607, C608, C609, C610, C611, C612, C613, C614, C615, C616, C617, C618, C619, C620, C621, C622, C623, C624, C625, C626, C627, C628, C629, C630, C631, C632, C633, C634, C635, C636, C637, C638, C639, C640, C641, C642, C643, C644, C645, C646, C647, C648, C649: CL21B105KAFNNNE; C_0603_1608Metric
C26, C27, C29, C30, C31, C32, C33, C34: 0.1uF_0603_16V; C_0603_1608Metric
C28, C650, C651, C652, C653, C654, C655, C656: CL21A106KAYNNNE; C_0805_2012Metric
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

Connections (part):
DATA1: J1.8, U2.2
DATA2: D321.4 (DIN), J1.7, R2.1, U3.2
DATA3: D641.4 (DIN), J1.6, R5.1, U4.2
DATA4: D961.4 (DIN), J1.5, R6.1, U5.2
DATA5: D1281.4 (DIN), J1.4, R7.1, U6.2
DATA6: D1601.4 (DIN), J1.3, R8.1, U7.2
DATA7: D1921.4 (DIN), J1.2, R9.1, U8.2
DATA8: D2241.4 (DIN), J1.1, R10.1, U9.2
GND: C1.2, C2.2, C3.2, C4.2, C5.2, C6.2, C7.2, C8.2, C9.2, C10.2, C11.2, C12.2, C13.2, C14.2, C15.2, C16.2, C17.2, C18.2, C19.2, C20.2, C21.2, C22.2, C23.2, C24.2, C25.2, C26.2, C27.2, C28.2, C29.2, C30.2, C31.2, C32.2, C33.2, C34.2, C35.2, C36.2, C37.2, C38.2, C39.2, C40.2, C41.2, C42.2, C43.2, C44.2, C45.2, C46.2, C47.2, C48.2, C49.2, C50.2, C51.2, C52.2, C53.2, C54.2, C55.2, C56.2, C57.2, C58.2, C59.2, C60.2, C61.2, C62.2, C63.2, C64.2, C65.2, C66.2, C67.2, C68.2, C69.2, C70.2, C71.2, C72.2, C73.2, C74.2, C75.2, C76.2, C77.2, C78.2, C79.2, C80.2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
unnamed: D5.1 (DOUT), D6.4 (DIN)
unnamed: D6.1 (DOUT), D7.4 (DIN)
unnamed: D7.1 (DOUT), D8.4 (DIN)
unnamed: D8.1 (DOUT), D9.4 (DIN)
unnamed: D9.1 (DOUT), D10.4 (DIN)
unnamed: D10.1 (DOUT), D11.4 (DIN)
unnamed: D11.1 (DOUT), D12.4 (DIN)
unnamed: D12.1 (DOUT), D13.4 (DIN)
unnamed: D13.1 (DOUT), D14.4 (DIN)
unnamed: D14.1 (DOUT), D15.4 (DIN)
unnamed: D15.1 (DOUT), D16.4 (DIN)
unnamed: D16.1 (DOUT), D17.4 (DIN)
unnamed: D17.1 (DOUT), D18.4 (DIN)
unnamed: D18.1 (DOUT), D19.4 (DIN)
unnamed: D19.1 (DOUT), D20.4 (DIN)
unnamed: D20.1 (DOUT), D21.4 (DIN)
unnamed: D21.1 (DOUT), D22.4 (DIN)
unnamed: D22.1 (DOUT), D23.4 (DIN)
unnamed: D23.1 (DOUT), D24.4 (DIN)
unnamed: D24.1 (DOUT), D25.4 (DIN)
unnamed: D25.1 (DOUT), D26.4 (DIN)
unnamed: D26.1 (DOUT), D27.4 (DIN)
unnamed: D27.1 (DOUT), D28.4 (DIN)
unnamed: D28.1 (DOUT), D29.4 (DIN)
unnamed: D29.1 (DOUT), D30.4 (DIN)
unnamed: D30.1 (DOUT), D31.4 (DIN)
unnamed: D31.1 (DOUT), D32.4 (DIN)
unnamed: D32.1 (DOUT), D33.4 (DIN)
unnamed: D33.1 (DOUT), D34.4 (DIN)
unnamed: D34.1 (DOUT), D35.4 (DIN)
unnamed: D35.1 (DOUT), D36.4 (DIN)
unnamed: D36.1 (DOUT), D37.4 (DIN)
unnamed: D37.1 (DOUT), D38.4 (DIN)
unnamed: D38.1 (DOUT), D39.4 (DIN)
unnamed: D39.1 (DOUT), D40.4 (DIN)
unnamed: D40.1 (DOUT), D41.4 (DIN)
unnamed: D41.1 (DOUT), D42.4 (DIN)
unnamed: D42.1 (DOUT), D43.4 (DIN)
unnamed: D43.1 (DOUT), D44.4 (DIN)
unnamed: D44.1 (DOUT), D45.4 (DIN)
unnamed: D45.1 (DOUT), D46.4 (DIN)
unnamed: D46.1 (DOUT), D47.4 (DIN)
unnamed: D47.1 (DOUT), D48.4 (DIN)
unnamed: D48.1 (DOUT), D49.4 (DIN)
unnamed: D49.1 (DOUT), D50.4 (DIN)
unnamed: D50.1 (DOUT), D51.4 (DIN)
unnamed: D51.1 (DOUT), D52.4 (DIN)
unnamed: D52.1 (DOUT), D53.4 (DIN)
unnamed: D53.1 (DOUT), D54.4 (DIN)
unnamed: D54.1 (DOUT), D55.4 (DIN)
unnamed: D55.1 (DOUT), D56.4 (DIN)
unnamed: D56.1 (DOUT), D57.4 (DIN)
unnamed: D57.1 (DOUT), D58.4 (DIN)
unnamed: D58.1 (DOUT), D59.4 (DIN)
unnamed: D59.1 (DOUT), D60.4 (DIN)
unnamed: D60.1 (DOUT), D61.4 (DIN)
unnamed: D61.1 (DOUT), D62.4 (DIN)
unnamed: D62.1 (DOUT), D63.4 (DIN)
unnamed: D63.1 (DOUT), D64.4 (DIN)
unnamed: D64.1 (DOUT), D65.4 (DIN)
unnamed: D65.1 (DOUT), D66.4 (DIN)
unnamed: D66.1 (DOUT), D67.4 (DIN)
unnamed: D67.1 (DOUT), D68.4 (DIN)
unnamed: D68.1 (DOUT), D69.4 (DIN)
unnamed: D69.1 (DOUT), D70.4 (DIN)
unnamed: D70.1 (DOUT), D71.4 (DIN)
unnamed: D71.1 (DOUT), D72.4 (DIN)
unnamed: D72.1 (DOUT), D73.4 (DIN)
unnamed: D73.1 (DOUT), D74.4 (DIN)
unnamed: D74.1 (DOUT), D75.4 (DIN)
unnamed: D75.1 (DOUT), D76.4 (DIN)
unnamed: D76.1 (DOUT), D77.4 (DIN)
unnamed: D77.1 (DOUT), D78.4 (DIN)
unnamed: D78.1 (DOUT), D79.4 (DIN)
unnamed: D79.1 (DOUT), D80.4 (DIN)
unnamed: D80.1 (DOUT), D81.4 (DIN)
unnamed: D81.1 (DOUT), D82.4 (DIN)
unnamed: D82.1 (DOUT), D83.4 (DIN)
unnamed: D83.1 (DOUT), D84.4 (DIN)
unnamed: D84.1 (DOUT), D85.4 (DIN)
unnamed: D85.1 (DOUT), D86.4 (DIN)
unnamed: D86.1 (DOUT), D87.4 (DIN)
unnamed: D87.1 (DOUT), D88.4 (DIN)
unnamed: D88.1 (DOUT), D89.4 (DIN)
unnamed: D89.1 (DOUT), D90.4 (DIN)
unnamed: D90.1 (DOUT), D91.4 (DIN)
unnamed: D91.1 (DOUT), D92.4 (DIN)
unnamed: D92.1 (DOUT), D93.4 (DIN)
unnamed: D93.1 (DOUT), D94.4 (DIN)
unnamed: D94.1 (DOUT), D95.4 (DIN)
unnamed: D95.1 (DOUT), D96.4 (DIN)
unnamed: D96.1 (DOUT), D97.4 (DIN)
unnamed: D97.1 (DOUT), D98.4 (DIN)
unnamed: D98.1 (DOUT), D99.4 (DIN)
unnamed: D99.1 (DOUT), D100.4 (DIN)
unnamed: D100.1 (DOUT), D101.4 (DIN)
unnamed: D101.1 (DOUT), D102.4 (DIN)
unnamed: D102.1 (DOUT), D103.4 (DIN)
unnamed: D103.1 (DOUT), D104.4 (DIN)
unnamed: D104.1 (DOUT), D105.4 (DIN)
unnamed: D105.1 (DOUT), D106.4 (DIN)
unnamed: D106.1 (DOUT), D107.4 (DIN)
unnamed: D107.1 (DOUT), D108.4 (DIN)
unnamed: D108.1 (DOUT), D109.4 (DIN)
unnamed: D109.1 (DOUT), D110.4 (DIN)
unnamed: D110.1 (DOUT), D111.4 (DIN)
unnamed: D111.1 (DOUT), D112.4 (DIN)
unnamed: D112.1 (DOUT), D113.4 (DIN)
unnamed: D113.1 (DOUT), D114.4 (DIN)
unnamed: D114.1 (DOUT), D115.4 (DIN)
unnamed: D115.1 (DOUT), D116.4 (DIN)
unnamed: D116.1 (DOUT), D117.4 (DIN)
unnamed: D117.1 (DOUT), D118.4 (DIN)
unnamed: D118.1 (DOUT), D119.4 (DIN)
unnamed: D119.1 (DOUT), D120.4 (DIN)
unnamed: D120.1 (DOUT), D121.4 (DIN)
unnamed: D121.1 (DOUT), D122.4 (DIN)
unnamed: D122.1 (DOUT), D123.4 (DIN)
unnamed: D123.1 (DOUT), D124.4 (DIN)
unnamed: D124.1 (DOUT), D125.4 (DIN)
unnamed: D125.1 (DOUT), D126.4 (DIN)
unnamed: D126.1 (DOUT), D127.4 (DIN)
unnamed: D127.1 (DOUT), D128.4 (DIN)
unnamed: D128.1 (DOUT), D129.4 (DIN)
unnamed: D129.1 (DOUT), D130.4 (DIN)
unnamed: D130.1 (DOUT), D131.4 (DIN)
unnamed: D131.1 (DOUT), D132.4 (DIN)
unnamed: D132.1 (DOUT), D133.4 (DIN)
unnamed: D133.1 (DOUT), D134.4 (DIN)
unnamed: D134.1 (DOUT), D135.4 (DIN)
unnamed: D135.1 (DOUT), D136.4 (DIN)
unnamed: D136.1 (DOUT), D137.4 (DIN)
unnamed: D137.1 (DOUT), D138.4 (DIN)
unnamed: D138.1 (DOUT), D139.4 (DIN)
unnamed: D139.1 (DOUT), D140.4 (DIN)
unnamed: D140.1 (DOUT), D141.4 (DIN)
unnamed: D141.1 (DOUT), D142.4 (DIN)
unnamed: D142.1 (DOUT), D143.4 (DIN)
unnamed: D143.1 (DOUT), D144.4 (DIN)
unnamed: D144.1 (DOUT), D145.4 (DIN)
unnamed: D145.1 (DOUT), D146.4 (DIN)
unnamed: D146.1 (DOUT), D147.4 (DIN)
unnamed: D147.1 (DOUT), D148.4 (DIN)
unnamed: D148.1 (DOUT), D149.4 (DIN)
unnamed: D149.1 (DOUT), D150.4 (DIN)
unnamed: D150.1 (DOUT), D151.4 (DIN)
unnamed: D151.1 (DOUT), D152.4 (DIN)
unnamed: D152.1 (DOUT), D153.4 (DIN)
unnamed: D153.1 (DOUT), D154.4 (DIN)
unnamed: D154.1 (DOUT), D155.4 (DIN)
unnamed: D155.1 (DOUT), D156.4 (DIN)
unnamed: D156.1 (DOUT), D157.4 (DIN)
unnamed: D157.1 (DOUT), D158.4 (DIN)
unnamed: D158.1 (DOUT), D159.4 (DIN)
unnamed: D159.1 (DOUT), D160.4 (DIN)
unnamed: D160.1 (DOUT), D161.4 (DIN)
unnamed: D161.1 (DOUT), D162.4 (DIN)
unnamed: D162.1 (DOUT), D163.4 (DIN)
unnamed: D163.1 (DOUT), D164.4 (DIN)
unnamed: D164.1 (DOUT), D165.4 (DIN)
unnamed: D165.1 (DOUT), D166.4 (DIN)
unnamed: D166.1 (DOUT), D167.4 (DIN)
unnamed: D167.1 (DOUT), D168.4 (DIN)
unnamed: D168.1 (DOUT), D169.4 (DIN)
unnamed: D169.1 (DOUT), D170.4 (DIN)
unnamed: D170.1 (DOUT), D171.4 (DIN)
unnamed: D171.1 (DOUT), D172.4 (DIN)
unnamed: D172.1 (DOUT), D173.4 (DIN)
unnamed: D173.1 (DOUT), D174.4 (DIN)
unnamed: D174.1 (DOUT), D175.4 (DIN)
unnamed: D175.1 (DOUT), D176.4 (DIN)
unnamed: D176.1 (DOUT), D177.4 (DIN)
unnamed: D177.1 (DOUT), D178.4 (DIN)
unnamed: D178.1 (DOUT), D179.4 (DIN)
unnamed: D179.1 (DOUT), D180.4 (DIN)
unnamed: D180.1 (DOUT), D181.4 (DIN)
unnamed: D181.1 (DOUT), D182.4 (DIN)
unnamed: D182.1 (DOUT), D183.4 (DIN)
unnamed: D183.1 (DOUT), D184.4 (DIN)
unnamed: D184.1 (DOUT), D185.4 (DIN)
unnamed: D185.1 (DOUT), D186.4 (DIN)
unnamed: D186.1 (DOUT), D187.4 (DIN)
unnamed: D187.1 (DOUT), D188.4 (DIN)
unnamed: D188.1 (DOUT), D189.4 (DIN)
unnamed: D189.1 (DOUT), D190.4 (DIN)
unnamed: D190.1 (DOUT), D191.4 (DIN)
unnamed: D191.1 (DOUT), D192.4 (DIN)
unnamed: D192.1 (DOUT), D193.4 (DIN)
unnamed: D193.1 (DOUT), D194.4 (DIN)
unnamed: D194.1 (DOUT), D195.4 (DIN)
unnamed: D195.1 (DOUT), D196.4 (DIN)
unnamed: D196.1 (DOUT), D197.4 (DIN)
unnamed: D197.1 (DOUT), D198.4 (DIN)
unnamed: D198.1 (DOUT), D199.4 (DIN)
unnamed: D199.1 (DOUT), D200.4 (DIN)
unnamed: D200.1 (DOUT), D201.4 (DIN)
unnamed: D201.1 (DOUT), D202.4 (DIN)
unnamed: D202.1 (DOUT), D203.4 (DIN)
unnamed: D203.1 (DOUT), D204.4 (DIN)
unnamed: D204.1 (DOUT), D205.4 (DIN)
unnamed: D205.1 (DOUT), D206.4 (DIN)
unnamed: D206.1 (DOUT), D207.4 (DIN)
unnamed: D207.1 (DOUT), D208.4 (DIN)
unnamed: D208.1 (DOUT), D209.4 (DIN)
unnamed: D209.1 (DOUT), D210.4 (DIN)
unnamed: D210.1 (DOUT), D211.4 (DIN)
unnamed: D211.1 (DOUT), D212.4 (DIN)
unnamed: D212.1 (DOUT), D213.4 (DIN)
unnamed: D213.1 (DOUT), D214.4 (DIN)
unnamed: D214.1 (DOUT), D215.4 (DIN)
unnamed: D215.1 (DOUT), D216.4 (DIN)
unnamed: D216.1 (DOUT), D217.4 (DIN)
unnamed: D217.1 (DOUT), D218.4 (DIN)
unnamed: D218.1 (DOUT), D219.4 (DIN)
unnamed: D219.1 (DOUT), D220.4 (DIN)
unnamed: D220.1 (DOUT), D221.4 (DIN)
unnamed: D221.1 (DOUT), D222.4 (DIN)
unnamed: D222.1 (DOUT), D223.4 (DIN)
unnamed: D223.1 (DOUT), D224.4 (DIN)
unnamed: D224.1 (DOUT), D225.4 (DIN)
unnamed: D225.1 (DOUT), D226.4 (DIN)
unnamed: D226.1 (DOUT), D227.4 (DIN)
unnamed: D227.1 (DOUT), D228.4 (DIN)
unnamed: D228.1 (DOUT), D229.4 (DIN)
unnamed: D229.1 (DOUT), D230.4 (DIN)
unnamed: D230.1 (DOUT), D231.4 (DIN)
unnamed: D231.1 (DOUT), D232.4 (DIN)
unnamed: D232.1 (DOUT), D233.4 (DIN)
unnamed: D233.1 (DOUT), D234.4 (DIN)
unnamed: D234.1 (DOUT), D235.4 (DIN)
unnamed: D235.1 (DOUT), D236.4 (DIN)
unnamed: D236.1 (DOUT), D237.4 (DIN)
unnamed: D237.1 (DOUT), D238.4 (DIN)
unnamed: D238.1 (DOUT), D239.4 (DIN)
unnamed: D239.1 (DOUT), D240.4 (DIN)
unnamed: D240.1 (DOUT), D241.4 (DIN)
unnamed: D241.1 (DOUT), D242.4 (DIN)
unnamed: D242.1 (DOUT), D243.4 (DIN)
unnamed: D243.1 (DOUT), D244.4 (DIN)
unnamed: D244.1 (DOUT), D245.4 (DIN)
unnamed: D245.1 (DOUT), D246.4 (DIN)
unnamed: D246.1 (DOUT), D247.4 (DIN)
unnamed: D247.1 (DOUT), D248.4 (DIN)
unnamed: D248.1 (DOUT), D249.4 (DIN)
unnamed: D249.1 (DOUT), D250.4 (DIN)
unnamed: D250.1 (DOUT), D251.4 (DIN)
unnamed: D251.1 (DOUT), D252.4 (DIN)
unnamed: D252.1 (DOUT), D253.4 (DIN)
unnamed: D253.1 (DOUT), D254.4 (DIN)
unnamed: D254.1 (DOUT), D255.4 (DIN)
unnamed: D255.1 (DOUT), D256.4 (DIN)
unnamed: D256.1 (DOUT), D257.4 (DIN)
unnamed: D257.1 (DOUT), D258.4 (DIN)
unnamed: D258.1 (DOUT), D259.4 (DIN)
unnamed: D259.1 (DOUT), D260.4 (DIN)
unnamed: D260.1 (DOUT), D261.4 (DIN)
unnamed: D261.1 (DOUT), D262.4 (DIN)
unnamed: D262.1 (DOUT), D263.4 (DIN)
unnamed: D263.1 (DOUT), D264.4 (DIN)
unnamed: D264.1 (DOUT), D265.4 (DIN)
unnamed: D265.1 (DOUT), D266.4 (DIN)
unnamed: D266.1 (DOUT), D267.4 (DIN)
unnamed: D267.1 (DOUT), D268.4 (DIN)
unnamed: D268.1 (DOUT), D269.4 (DIN)
unnamed: D269.1 (DOUT), D270.4 (DIN)
unnamed: D270.1 (DOUT), D271.4 (DIN)
unnamed: D271.1 (DOUT), D272.4 (DIN)
unnamed: D272.1 (DOUT), D273.4 (DIN)
unnamed: D273.1 (DOUT), D274.4 (DIN)
unnamed: D274.1 (DOUT), D275.4 (DIN)
unnamed: D275.1 (DOUT), D276.4 (DIN)
unnamed: D276.1 (DOUT), D277.4 (DIN)
unnamed: D277.1 (DOUT), D278.4 (DIN)
unnamed: D278.1 (DOUT), D279.4 (DIN)
unnamed: D279.1 (DOUT), D280.4 (DIN)
unnamed: D280.1 (DOUT), D281.4 (DIN)
unnamed: D281.1 (DOUT), D282.4 (DIN)
unnamed: D282.1 (DOUT), D283.4 (DIN)
unnamed: D283.1 (DOUT), D284.4 (DIN)
unnamed: D284.1 (DOUT), D285.4 (DIN)
unnamed: D285.1 (DOUT), D286.4 (DIN)
unnamed: D286.1 (DOUT), D287.4 (DIN)
unnamed: D287.1 (DOUT), D288.4 (DIN)
unnamed: D288.1 (DOUT), D289.4 (DIN)
unnamed: D289.1 (DOUT), D290.4 (DIN)
unnamed: D290.1 (DOUT), D291.4 (DIN)
unnamed: D291.1 (DOUT), D292.4 (DIN)
unnamed: D292.1 (DOUT), D293.4 (DIN)
unnamed: D293.1 (DOUT), D294.4 (DIN)
unnamed: D294.1 (DOUT), D295.4 (DIN)
unnamed: D295.1 (DOUT), D296.4 (DIN)
unnamed: D296.1 (DOUT), D297.4 (DIN)
unnamed: D297.1 (DOUT), D298.4 (DIN)
unnamed: D298.1 (DOUT), D299.4 (DIN)
unnamed: D299.1 (DOUT), D300.4 (DIN)
unnamed: D300.1 (DOUT), D301.4 (DIN)
unnamed: D301.1 (DOUT), D302.4 (DIN)
unnamed: D302.1 (DOUT), D303.4 (DIN)
unnamed: D303.1 (DOUT), D304.4 (DIN)
unnamed: D304.1 (DOUT), D305.4 (DIN)
unnamed: D305.1 (DOUT), D306.4 (DIN)
unnamed: D306.1 (DOUT), D307.4 (DIN)
unnamed: D307.1 (DOUT), D308.4 (DIN)
unnamed: D308.1 (DOUT), D309.4 (DIN)
unnamed: D309.1 (DOUT), D310.4 (DIN)
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

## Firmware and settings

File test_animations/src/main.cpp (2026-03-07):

#include <FastLED.h>

// LED Matrix Configuration
#define MATRIX_WIDTH 10
#define MATRIX_HEIGHT 10
#define NUM_LEDS_PER_STRIP 50  // Each strip has 50 LEDs (half of 100)
#define LED_PIN_1 13  // D13
#define LED_PIN_2 12  // D12
#define LED_TYPE WS2812B
#define COLOR_ORDER GRB

// Game Configuration
#define SNAKE_SPEED 150  // milliseconds between moves (faster for optimal play)
#define INITIAL_SNAKE_LENGTH 3

CRGB leds1[NUM_LEDS_PER_STRIP];
CRGB leds2[NUM_LEDS_PER_STRIP];

// Snake game variables
struct Point {
  int x;
  int y;
};

Point snake[100];
int snakeLength = INITIAL_SNAKE_LENGTH;
Point food;
int direction = 0; // 0=right, 1=down, 2=left, 3=up
CRGB snakeColor = CRGB::Green;
CRGB foodColor = CRGB::Red;
int colorHue = 0;  // For cycling through colors
unsigned long lastMoveTime = 0;
bool gameOver = false;
int highScore = INITIAL_SNAKE_LENGTH;
int foodEaten = 0;

// Forward declarations
void moveSnake();
void autoNavigate();
void checkCollisions();
void placeFood();
void displayGame();
void setPixel(int x, int y, CRGB color);
void gameOverAnimation();
void resetGame();
bool isSafe(int x, int y);
int getDirection(Point from, Point to);
bool findPathAStar(Point start, Point goal, Point path[], int &pathLength);
int manhattanDistance(Point a, Point b);
void getSafeNeighbors(Point current, Point neighbors[], int &count);
int getBestSafeDirection();

void setup() {
  Serial.begin(115200);

  // Initialize LED strips
  FastLED.addLeds<LED_TYPE, LED_PIN_1, COLOR_ORDER>(leds1, NUM_LEDS_PER_STRIP);
  FastLED.addLeds<LED_TYPE, LED_PIN_2, COLOR_ORDER>(leds2, NUM_LEDS_PER_STRIP);
  FastLED.setBrightness(50);

  // Initialize snake in the middle
  for(int i = 0; i < snakeLength; i++) {
    snake[i].x = 5 - i;
    snake[i].y = 5;
  }

  // Place first food
  placeFood();

  Serial.println("Snake Game Started!");
  Serial.println("10x10 LED Matrix - Split across D13 and D12");
  Serial.println("AI Mode: Optimal Pathfinding (A*)");
  Serial.println("Goal: Survive as long as possible!\n");
}

void loop() {
  if(gameOver) {
    gameOverAnimation();
    delay(3000);
    resetGame();
    return;
  }

  // Cycle food color continuously
  colorHue = (colorHue + 1) % 256;
  foodColor = CHSV(colorHue, 255, 255);

  // Move snake at defined speed
  if(millis() - lastMoveTime > SNAKE_SPEED) {
    lastMoveTime = millis();
    moveSnake();
    checkCollisions();
  }

  // Update display
  displayGame();
  FastLED.show();
  delay(10);
}

void moveSnake() {
  // Calculate new head position
  Point newHead = snake[0];

  switch(direction) {
    case 0: newHead.x++; break; // right
    case 1: newHead.y++; break; // down
    case 2: newHead.x--; break; // left
    case 3: newHead.y--; break; // up
  }

  // Wrap around edges
  if(newHead.x < 0) newHead.x = MATRIX_WIDTH - 1;
  if(newHead.x >= MATRIX_WIDTH) newHead.x = 0;
  if(newHead.y < 0) newHead.y = MATRIX_HEIGHT - 1;
  if(newHead.y >= MATRIX_HEIGHT) newHead.y = 0;

  // Check if eating food
  bool ateFood = (newHead.x == food.x && newHead.y == food.y);

  if(ateFood) {
    // Snake grows and changes color to food color
    snakeColor = foodColor;
    snakeLength++;
    foodEaten++;
    placeFood();

    if(snakeLength > highScore) {
      highScore = snakeLength;
      Serial.printf("🏆 NEW HIGH SCORE: %d!\n", highScore);
    } else {
      Serial.printf("Food #%d eaten! Length: %d (High: %d)\n", foodEaten, snakeLength, highScore);
    }
  }

  // Move snake body
  for(int i = snakeLength - 1; i > 0; i--) {
    snake[i] = snake[i-1];
  }
  snake[0] = newHead;

  // Change direction automatically (simple AI for demo)
  autoNavigate();
}

void autoNavigate() {
  // Try A* pathfinding first
  Point path[100];
  int pathLength = 0;

  if(findPathAStar(snake[0], food, path, pathLength) && pathLength > 1) {
    // Follow the A* path
    direction = getDirection(snake[0], path[1]);
    return;
  }

  // Fallback: Pick the safest direction
  direction = getBestSafeDirection();
}

bool isSafe(int x, int y) {
  // Wrap coordinates
  if(x < 0) x = MATRIX_WIDTH - 1;
  if(x >= MATRIX_WIDTH) x = 0;
  if(y < 0) y = MATRIX_HEIGHT - 1;
  if(y >= MATRIX_HEIGHT) y = 0;

  // Check if position is occupied by snake body (not tail, as it will move)
  for(int i = 0; i < snakeLength - 1; i++) {
    if(snake[i].x == x && snake[i].y == y) {
      return false;
    }
  }
  return true;
}

int getDirection(Point from, Point to) {
  // Calculate direction from 'from' to 'to' considering wrap-around
  int dx = to.x - from.x;
  int dy = to.y - from.y;

  // Handle wrap-around
  if(abs(dx) > MATRIX_WIDTH/2) dx = dx > 0 ? dx - MATRIX_WIDTH : dx + MATRIX_WIDTH;
  if(abs(dy) > MATRIX_HEIGHT/2) dy = dy > 0 ? dy - MATRIX_HEIGHT : dy + MATRIX_HEIGHT;

  // Prioritize larger distance
  if(abs(dx) >= abs(dy)) {
    return (dx > 0) ? 0 : 2; // right or left
  } else {
    return (dy > 0) ? 1 : 3; // down or up
  }
}

int manhattanDistance(Point a, Point b) {
  int dx = abs(a.x - b.x);
  int dy = abs(a.y - b.y);

  // Handle wrap-around
  if(dx > MATRIX_WIDTH/2) dx = MATRIX_WIDTH - dx;
  if(dy > MATRIX_HEIGHT/2) dy = MATRIX_HEIGHT - dy;

  return dx + dy;
}

void getSafeNeighbors(Point current, Point neighbors[], int &count) {
  count = 0;

  // Four directions: right, down, left, up
  int dx[] = {1, 0, -1, 0};
  int dy[] = {0, 1, 0, -1};

  for(int i = 0; i < 4; i++) {
    int nx = current.x + dx[i];
    int ny = current.y + dy[i];

    // Wrap around
    if(nx < 0) nx = MATRIX_WIDTH - 1;
    if(nx >= MATRIX_WIDTH) nx = 0;
    if(ny < 0) ny = MATRIX_HEIGHT - 1;
    if(ny >= MATRIX_HEIGHT) ny = 0;

    if(isSafe(nx, ny)) {
      neighbors[count].x = nx;
      neighbors[count].y = ny;
      count++;
    }
  }
}

bool findPathAStar(Point start, Point goal, Point path[], int &pathLength) {
  // Simple A* implementation for small 10x10 grid
  const int MAX_NODES = 100;
  Point openSet[MAX_NODES];
  int openCount = 0;

  bool closedSet[MATRIX_WIDTH][MATRIX_HEIGHT] = {false};
  int gScore[MATRIX_WIDTH][MATRIX_HEIGHT];
  int fScore[MATRIX_WIDTH][MATRIX_HEIGHT];
  Point cameFrom[MATRIX_WIDTH][MATRIX_HEIGHT];
  bool hasParent[MATRIX_WIDTH][MATRIX_HEIGHT] = {false};

  // Initialize scores
  for(int i = 0; i < MATRIX_WIDTH; i++) {
    for(int j = 0; j < MATRIX_HEIGHT; j++) {
      gScore[i][j] = 10000;
      fScore[i][j] = 10000;
    }
  }

  // Start node
  openSet[0] = start;
  openCount = 1;
  gScore[start.x][start.y] = 0;
  fScore[start.x][start.y] = manhattanDistance(start, goal);

  while(openCount > 0) {
    // Find node with lowest fScore in openSet
    int currentIdx = 0;
    for(int i = 1; i < openCount; i++) {
      if(fScore[openSet[i].x][openSet[i].y] < fScore[openSet[currentIdx].x][openSet[currentIdx].y]) {
        currentIdx = i;
      }
    }

    Point current = openSet[currentIdx];

    // Check if we reached the goal
    if(current.x == goal.x && current.y == goal.y) {
      // Reconstruct path
      pathLength = 0;
      Point step = goal;
      while(hasParent[step.x][step.y]) {
        path[pathLength++] = step;
        step = cameFrom[step.x][step.y];
      }
      path[pathLength++] = start;

      // Reverse path
      for(int i = 0; i < pathLength / 2; i++) {
        Point temp = path[i];
        path[i] = path[pathLength - 1 - i];
        path[pathLength - 1 - i] = temp;
      }

      return true;
    }

    // Move current from open to closed
    closedSet[current.x][current.y] = true;
    for(int i = currentIdx; i < openCount - 1; i++) {
      openSet[i] = openSet[i + 1];
    }
    openCount--;

    // Check neighbors
    Point neighbors[4];
    int neighborCount = 0;
    getSafeNeighbors(current, neighbors, neighborCount);

    for(int i = 0; i < neighborCount; i++) {
      Point neighbor = neighbors[i];

      if(closedSet[neighbor.x][neighbor.y]) continue;

      int tentativeGScore = gScore[current.x][current.y] + 1;

      // Check if neighbor is in openSet
      bool inOpenSet = false;
      for(int j = 0; j < openCount; j++) {
        if(openSet[j].x == neighbor.x && openSet[j].y == neighbor.y) {
          inOpenSet = true;
          break;
        }
      }

      if(!inOpenSet) {
        if(openCount < MAX_NODES) {
          openSet[openCount++] = neighbor;
        }
      } else if(tentativeGScore >= gScore[neighbor.x][neighbor.y]) {
        continue;
      }

      // This path is the best so far
      cameFrom[neighbor.x][neighbor.y] = current;
      hasParent[neighbor.x][neighbor.y] = true;
      gScore[neighbor.x][neighbor.y] = tentativeGScore;
      fScore[neighbor.x][neighbor.y] = gScore[neighbor.x][neighbor.y] + manhattanDistance(neighbor, goal);
    }
  }

  // No path found
  return false;
}

int getBestSafeDirection() {
  // If A* fails, pick direction that maximizes space/distance from tail
  Point head = snake[0];
  int bestDir = direction; // Keep current direction as default
  int bestScore = -1;

  // Try all 4 directions
  int dx[] = {1, 0, -1, 0};
  int dy[] = {0, 1, 0, -1};

  for(int i = 0; i < 4; i++) {
    int nx = head.x + dx[i];
    int ny = head.y + dy[i];

    // Wrap around
    if(nx < 0) nx = MATRIX_WIDTH - 1;
    if(nx >= MATRIX_WIDTH) nx = 0;
    if(ny < 0) ny = MATRIX_HEIGHT - 1;
    if(ny >= MATRIX_HEIGHT) ny = 0;

    if(!isSafe(nx, ny)) continue;

    // Score based on distance to food and available space
    Point testPos = {nx, ny};
    int score = 0;

    // Prefer directions that lead toward food
    int distToFood = manhattanDistance(testPos, food);
    score += (50 - distToFood * 2); // Closer to food = better

    // Prefer directions with more space (count safe neighbors)
    Point neighbors[4];
    int count = 0;
    getSafeNeighbors(testPos, neighbors, count);
    score += count * 10; // More escape routes = better

    if(score > bestScore) {
      bestScore = score;
      bestDir = i;
    }
  }

  return bestDir;
}

void checkCollisions() {
  // Check if snake hits itself
  Point head = snake[0];
  for(int i = 1; i < snakeLength; i++) {
    if(head.x == snake[i].x && head.y == snake[i].y) {
      gameOver = true;
      Serial.println("\n════════════════════════════════");
      Serial.println("        GAME OVER");
      Serial.println("════════════════════════════════");
      Serial.printf("Final Length: %d\n", snakeLength);
      Serial.printf("Food Eaten: %d\n", foodEaten);
      Serial.printf("High Score: %d\n", highScore);
      Serial.printf("Coverage: %.1f%%\n", (snakeLength * 100.0) / (MATRIX_WIDTH * MATRIX_HEIGHT));
      Serial.println("════════════════════════════════\n");
      return;
    }
  }
}

void placeFood() {
  bool validPosition = false;
  while(!validPosition) {
    food.x = random(MATRIX_WIDTH);
    food.y = random(MATRIX_HEIGHT);

    // Check if food is on snake
    validPosition = true;
    for(int i = 0; i < snakeLength; i++) {
      if(food.x == snake[i].x && food.y == snake[i].y) {
        validPosition = false;
        break;
      }
    }
  }
}

void displayGame() {
  // Clear all LEDs
  fill_solid(leds1, NUM_LEDS_PER_STRIP, CRGB::Black);
  fill_solid(leds2, NUM_LEDS_PER_STRIP, CRGB::Black);

  // Draw snake
  for(int i = 0; i < snakeLength; i++) {
    // Fade tail
    int brightness = 255 - (i * 10);
    if(brightness < 50) brightness = 50;
    CRGB color = snakeColor;
    color.nscale8(brightness);

    setPixel(snake[i].x, snake[i].y, color);
  }

  // Draw food (pulsing effect)
  int foodBrightness = 128 + 127 * sin(millis() / 100.0);
  CRGB pulseFoodColor = foodColor;
  pulseFoodColor.nscale8(foodBrightness);
  setPixel(food.x, food.y, pulseFoodColor);
}

void setPixel(int x, int y, CRGB color) {
  // Convert x,y coordinates to LED index
  // Assuming serpentine/zigzag layout
  int ledIndex;

  if(y % 2 == 0) {
    // Even rows go left to right
    ledIndex = y * MATRIX_WIDTH + x;
  } else {
    // Odd rows go right to left
    ledIndex = y * MATRIX_WIDTH + (MATRIX_WIDTH - 1 - x);
  }

  // Split between two strips
  if(ledIndex < NUM_LEDS_PER_STRIP) {
    leds1[ledIndex] = color;
  } else {
    leds2[ledIndex - NUM_LEDS_PER_STRIP] = color;
  }
}

void gameOverAnimation() {
  // Flash red a few times
  for(int i = 0; i < 3; i++) {
    fill_solid(leds1, NUM_LEDS_PER_STRIP, CRGB::Red);
    fill_solid(leds2, NUM_LEDS_PER_STRIP, CRGB::Red);
    FastLED.show();
    delay(300);

    fill_solid(leds1, NUM_LEDS_PER_STRIP, CRGB::Black);
    fill_solid(leds2, NUM_LEDS_PER_STRIP, CRGB::Black);
    FastLED.show();
    delay(300);
  }
}

void resetGame() {
  snakeLength = INITIAL_SNAKE_LENGTH;
  direction = 0;
  snakeColor = CRGB::Green;
  gameOver = false;
  foodEaten = 0;

  // Reset snake position
  for(int i = 0; i < snakeLength; i++) {
    snake[i].x = 5 - i;
    snake[i].y = 5;
  }

  placeFood();
  Serial.println("\n🔄 Game Reset - Trying again with optimal AI...\n");
}

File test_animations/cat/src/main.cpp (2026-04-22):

#include <FastLED.h>

// ============================================================================
// A Day in the Life of a Cat
// ----------------------------------------------------------------------------
// Multi-scene animation for a 10x10 WS2812B matrix (serpentine, two strips).
// Scenes cycle: blink -> laser chase -> pounce -> knock cup -> sleep -> repeat
// ============================================================================

#define MATRIX_WIDTH       10
#define MATRIX_HEIGHT      10
#define NUM_LEDS_PER_STRIP 50
#define LED_PIN_1          13
#define LED_PIN_2          12
#define LED_TYPE           WS2812B
#define COLOR_ORDER        GRB

CRGB leds1[NUM_LEDS_PER_STRIP];
CRGB leds2[NUM_LEDS_PER_STRIP];
CRGB frame[MATRIX_WIDTH][MATRIX_HEIGHT];

// Cat palette (ginger tabby, because they have the most personality)
const CRGB FUR         = CRGB(255, 110,  20);
const CRGB FUR_SHADE   = CRGB(140,  55,   8);
const CRGB FUR_BELLY   = CRGB(255, 180,  90);
const CRGB EYE_GREEN   = CRGB( 80, 255,  40);
const CRGB EYE_SLIT    = CRGB(255, 230,  60);
const CRGB NOSE        = CRGB(255, 100, 140);
const CRGB WHISKER     = CRGB( 80,  80,  80);
const CRGB LASER       = CRGB(255,   0,   0);
const CRGB LASER_GLOW  = CRGB(120,   0,   0);
const CRGB ZZZ         = CRGB( 90, 140, 255);
const CRGB CUP         = CRGB(120, 200, 255);
const CRGB TABLE       = CRGB( 90,  60,  30);
const CRGB DUST        = CRGB(200, 180, 120);

enum Scene {
  SCENE_FACE    = 0,
  SCENE_LASER   = 1,
  SCENE_POUNCE  = 2,
  SCENE_KNOCK   = 3,
  SCENE_SLEEP   = 4,
  SCENE_COUNT
};

const unsigned long SCENE_MS[SCENE_COUNT] = {
  5000,  // face / blinking
  7000,  // laser chase
  4500,  // pounce
  6000,  // knocking the cup off
  6500,  // sleeping
};

int           currentScene = SCENE_FACE;
unsigned long sceneStart   = 0;

// ---------------------------------------------------------------------------
// Frame buffer helpers
// ---------------------------------------------------------------------------

void clearFrame() {
  for (int x = 0; x < MATRIX_WIDTH; x++)
    for (int y = 0; y < MATRIX_HEIGHT; y++)
      frame[x][y] = CRGB::Black;
}

void putPixel(int x, int y, CRGB c) {
  if (x < 0 || x >= MATRIX_WIDTH || y < 0 || y >= MATRIX_HEIGHT) return;
  frame[x][y] = c;
}

// Serpentine mapping identical to the snake demo so this runs on the same hw.
void pushFrame() {
  for (int y = 0; y < MATRIX_HEIGHT; y++) {
    for (int x = 0; x < MATRIX_WIDTH; x++) {
      int idx = (y % 2 == 0)
              ? y * MATRIX_WIDTH + x
              : y * MATRIX_WIDTH + (MATRIX_WIDTH - 1 - x);
      CRGB c = frame[x][y];
      if (idx < NUM_LEDS_PER_STRIP) leds1[idx] = c;
      else                          leds2[idx - NUM_LEDS_PER_STRIP] = c;
    }
  }
  FastLED.show();
}

// ---------------------------------------------------------------------------
// SCENE 1 — Big cat face with slow blinks and occasional slit-eye moods
// ---------------------------------------------------------------------------
// Sprite legend: 0=off  1=fur  2=belly  3=eye  4=nose  5=whisker
static const uint8_t CAT_FACE[10][10] = {
  {0,0,1,0,0,0,0,1,0,0},
  {0,1,1,1,0,0,1,1,1,0},
  {1,1,1,1,1,1,1,1,1,1},
  {1,1,1,1,1,1,1,1,1,1},
  {1,1,3,1,2,2,1,3,1,1},
  {1,1,1,2,2,2,2,1,1,1},
  {5,1,1,2,4,4,2,1,1,5},
  {5,1,1,1,2,2,1,1,1,5},
  {0,1,1,1,1,1,1,1,1,0},
  {0,0,1,1,1,1,1,1,0,0},
};

void drawCatFace(unsigned long t) {
  // Full blink every 2.5s, lasting ~180ms. Plus a slow "love blink" occasionally.
  unsigned long cycle = t % 2500;
  bool blinking = cycle < 180;
  // Every ~10s, the cat squints (slit eyes) for a beat.
  bool squint = (t % 10000) < 700 && !blinking;

  for (int y = 0; y < 10; y++) {
    for (int x = 0; x < 10; x++) {
      CRGB c = CRGB::Black;
      switch (CAT_FACE[y][x]) {
        case 1: c = FUR;        break;
        case 2: c = FUR_BELLY;  break;
        case 3: c = blinking ? FUR : (squint ? EYE_SLIT : EYE_GREEN); break;
        case 4: c = NOSE;       break;
        case 5: c = WHISKER;    break;
      }
      putPixel(x, y, c);
    }
  }

  // Purr: very subtle overall brightness pulse (chest rumbles)
  uint8_t purr = 230 + (uint8_t)(25.0 * sin(t / 180.0));
  for (int y = 0; y < 10; y++)
    for (int x = 0; x < 10; x++)
      frame[x][y].nscale8(purr);
}

// ---------------------------------------------------------------------------
// SCENE 2 — Laser chase: a 3x3 cat hunts a darting red dot
// ---------------------------------------------------------------------------
// The laser jitters with tiny darts plus occasional big teleports.
// The cat follows the laser with some delay and a springy overshoot.

struct V { float x, y; };

void drawLaserChase(unsigned long t) {
  static bool    initialised = false;
  static V       laser = {5, 5};
  static V       cat   = {1, 8};
  static uint32_t lastTeleport = 0;
  static uint32_t lastJitter   = 0;

  if (!initialised) {
    initialised = true;
    laser = {5, 5};
    cat   = {1, 8};
    lastTeleport = millis();
    lastJitter   = millis();
  }

  // Jitter the laser a bit every 80ms
  uint32_t now = millis();
  if (now - lastJitter > 80) {
    lastJitter = now;
    laser.x += (random(-100, 101) / 100.0f) * 1.2f;
    laser.y += (random(-100, 101) / 100.0f) * 1.2f;
  }
  // Every 700-1400ms the laser teleports somewhere fresh to taunt the cat
  if (now - lastTeleport > (uint32_t)random(700, 1400)) {
    lastTeleport = now;
    laser.x = random(0, MATRIX_WIDTH);
    laser.y = random(0, MATRIX_HEIGHT);
  }
  if (laser.x < 0) laser.x = 0;
  if (laser.x > 9) laser.x = 9;
  if (laser.y < 0) laser.y = 0;
  if (laser.y > 9) laser.y = 9;

  // Springy pursuit
  cat.x += (laser.x - cat.x) * 0.12f;
  cat.y += (laser.y - cat.y) * 0.12f;

  int cx = (int)round(cat.x);
  int cy = (int)round(cat.y);

  // 3x3 mini-cat: ears on top, body square, tail kink behind
  //   X . X        ears
  //   X X X        head/body
  //   . X .        paw
  static const int8_t mini[5][2] = {
    { 0, -1}, { 2, -1},             // ears
    { 0,  0}, { 1,  0}, { 2,  0},   // body
  };
  for (int i = 0; i < 5; i++) {
    putPixel(cx - 1 + mini[i][0], cy + mini[i][1], FUR);
  }
  // Tiny eyes on the middle row (x=cx-1+0 already fur; overwrite ears with eyes)
  putPixel(cx - 1, cy - 1, EYE_GREEN);
  putPixel(cx + 1, cy - 1, EYE_GREEN);
  // Wiggling tail behind the cat (opposite side from laser)
  int tailDir = (laser.x > cat.x) ? -1 : +1;
  int tailJog = ((t / 120) % 2) ? 0 : 1;
  putPixel(cx + 2 * tailDir,     cy,     FUR_SHADE);
  putPixel(cx + 2 * tailDir,     cy - tailJog, FUR_SHADE);

  // Laser glow + dot
  int lx = (int)round(laser.x);
  int ly = (int)round(laser.y);
  for (int dx = -1; dx <= 1; dx++)
    for (int dy = -1; dy <= 1; dy++)
      if (dx || dy) putPixel(lx + dx, ly + dy, LASER_GLOW);
  putPixel(lx, ly, LASER);
}
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

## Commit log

2026-02-04 kicad start
2026-02-05 Add KiCad library repositories list
2026-03-07 feat: finished test layout, example animations
    [led_bage_sample-B_Cu.gbr, led_bage_sample-B_Mask.gbr, led_bage_sample-B_Paste.gbr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]
2026-03-07 feat: include Arduino.h
2026-03-07 feat: fix directory clusterfuck
    [main.cpp]
2026-08-15 chore(nix): add development flake (#2)
    * chore(nix): add development flake
    `nix develop` provides the toolchain for all three parts of this repo, and
    `nix flake show` prints the command map (setup/build/test/lint/fmt/run) with a
    description per verb, so a newcomer does not have to read a README first.
    - KiCad 10.0.5 (kicad-small) plus CPython 3.14, wired together so `import
    pcbnew` works from a plain interpreter. 20 of the 22 Python files here need
    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
2026-10-17 feat: scale protection circuit toward 2500-LED main board
    Add Si7145DP P-FET (U1) and SnapEDA-imported library table (fp-lib-table)
    to the main board. WIP: U1 pin-to-net mapping is incorrect — drain pads
    currently land on VDD instead of VDD_S, so the FET is shorted across
    itself and not actually protecting anything yet.
    Add three pcbnew automation scripts to support the build:
    - stitch_power_planes.py: checkerboard via stitching across In1.Cu/In2.Cu
    - add_thermal_vias.py: drops thermal via grid under exposed pads
    - place_bulk_caps.py: clones a template cap across the LED bbox
    Sample board updated alongside the main board for prototyping continuity.
2026-10-17 feat: lay down 40x64 LED grid with fanout and decoupling
    Place 2560 LEDs in a 40-col x 64-row serpentine grid (8 data chains of
    320 LEDs each, snake continues across chain boundaries -- matches the
    sample's D50/D51 transition pattern).
    Drop C642..C649 from the schematic to bring the 0603 cap count from 648
    down to 640, matching the 20x32 = 640 2x2 LED-block count of the new
    grid (the previous 54x48 layout had 648 blocks).
    Run the LED-grid pipeline against the main board:
    - normalize LED rotation to 0 deg (idempotent)
    - 5120 power fanout vias placed on VDD_S / GND
    - 640 decoupling caps snapped to block centers on B.Cu, rotated 45 deg
    New: place_leds.py -- parameterized serpentine grid layo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
2026-10-17 feat: tighten zone fills and start data-lane routing
    Tighten In1.Cu (GND) and In2.Cu (VDD_S) zones to 0.15 mm clearance and
    0.15 mm min thickness so copper bridges between the per-LED fanout vias
    on the 1.5625 mm pitch instead of breaking into many islands. Both
    zones now refill as a single continuous fill region. Settings stay at
    JLC's 4-layer manufacturing minimum (6 mil), no fab risk.
    Place initial data-lane traces D1-D5 (L-to-R template, top of row 1)
    and D76-D80 (R-to-L template, end of row 2) for chain 1, manually
    routed in pcbnew. To be replicated across all rows by a follow-up
    script.
    Approximate existing-via radius with via_radius from the netclass in
    stitch_power_planes.py instea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
2026-10-17 feat: data-lane routing, via geometry fix, polymer cap placement
    Add replicate_data_routing.py: extracts an L-to-R and R-to-L track
    template from the schematic and stamps them across all 2496 in-row
    LED-pair segments. Handles both Net-(D[n]-DOUT) and Net-(D[n+1]-DIN)
    naming conventions that KiCad picks based on schematic ordering.
    Bring the Default netclass via geometry to 0.5/0.3 mm (0.1 mm annular
    ring) so vias meet JLC's 4-layer minimum. All 5274 existing vias
    resized accordingly. Fixed manually after pcbnew save reverted.
    Place 10x polymer bulk caps as 5 paired front+back stacks along the
    bottom edge of the LED grid, doubled-up so each pair shares its 16
    fanout vias. Trim U1 thermal vi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
2026-10-17 feat: rename LEDs per chain (DA..DH), add lanyard tabs, 6-layer stackup
    Renumber LED refs from sequential D1..D2560 (which broke JLC's <=2048
    ref-number cap on chain 8) to per-chain letter prefix DA1..DH320. Both
    schematic and PCB updated in lockstep via cad/renumber_leds.py. Also
    fixes the stale D2561 -> TVS1 sync that didn't propagate from the
    schematic.
    Add side tabs at top corners (10x12 mm, 3.5 mm hole each) for lanyard
    mounting. Currently T-shaped (top edge merged with main board) and
    bare-FR4 hole — flagged for structural redesign next session.
    Move to 6-layer stackup: F | GND | VDD_S | VDD_S | GND | B. Existing
    through-vias automatically pick up the duplicate inner planes; halves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
2026-10-17 chore: untrack KiCad local history and ignore generated files
    KiCad 10 keeps per-project local history as its own git repository in
    .history/. Both copies were committed as orphan gitlinks with no
    .gitmodules entry, so nobody else could ever fetch them. Untrack them and
    ignore .history/, DRC/ERC reports and Playwright MCP session logs.
2026-10-17 feat(mockup): add browser preview of the 40x64 LED grid
    Cycles through 11 test animations at the real grid size so the resolution
    can be judged before firmware exists. The Bad Apple clip is a symlink to
    test_animations/bad_apple.mp4 instead of a second 8.8 MB copy.
2026-10-17 docs(readme): reflect matrix PCB layout progress
    Document the mockup, the nix dev shell, the 6-layer stackup, on-board input
    protection, the implemented decoupling scheme, and replace the stale
    February roadmap with the current state.
2026-10-17 chore(cad): update KiCad project archives
    Refresh the main board archive to the 2026-04-30 layout and add the
    sample board v2 production archive.
2026-10-17 fix(cad): put U1 drain on the input so reverse polarity is blocked
    The P-FET was wired source-on-input, so its body diode conducted with a
    reversed plug and the protection did nothing. Drain (pins 5-8 + EP) now
    goes to VDD, source (pins 1-3) to VDD_S, R3 sits between gate and source.
    The fabricated 100-LED sample still has the old wiring.
2026-10-17 feat(cad): rounded 71x150 mm outline with lanyard holes and J2 top band
    - Edge.Cuts: plain rounded rectangle, R5 corners, no tabs.
    - H1/H2: 5 mm plated lanyard holes with GND ring, board-only footprints.
    - J2 centered in a new 16 mm top band, cable still exits the top edge.
    - Power entry re-laid with F/B VDD pours and a 24-via VDD_S field,
    following the U1 drain/source fix.
    - redesign_top_band.py generates it idempotently; test_board.py checks
    outline, holes, U1 nets, PTH mask openings and DRC with schematic parity.
2026-10-17 docs(readme): add matrix PCB layout image and option C specs
2026-10-30 chore(cad): fix ruff findings in layout scripts
    Mark the scripts executable, sort imports, and drop an unused variable
    and a redundant int() cast.
2026-10-30 feat(cad): silkscreen art and 0.1 mm fab design rules on the matrix board
    - Trace the artist's front and back layers (cad/art/*.png, exported from
    the PSD) into filled silkscreen polygons with add_silkscreen_art.py.
    - Raise the board clearance and track-width floor to 0.1 mm (PCBWay
    standard). Narrow the data tracks to the 0.1 mm Data netclass and move
    60 edge jogs off the LED pads (ADR 0003).
    - Correct the 1 uF caps to the 0603 part CL10B105KA8NNNC. Add
    manufacturer and part number fields for J1, J2, U1 and U2-U9.
    - Sync net names from the schematic.
2026-10-30 feat(cad): fab outputs with JLCPCB BOM/CPL and end-to-end checks
    export_fab.py writes 6-layer Gerbers and drill files, the BOM and the
    KiCad centroid to cad/fab/. It also writes JLCPCB files:
    - MPN to LCSC mapping, with stocked stand-ins where JLC can't place the
    designed part.
    - Bottom-side angles converted to JLC's view from below.
    - Per-footprint rotation and origin fixes, read off JLC's placement
    preview (ADR 0004).
    test_board.py checks the silkscreen art, the fab minimums, the fab
    outputs and the JLC placements. The stale 4-layer gerbers in cad/ are
    removed.
